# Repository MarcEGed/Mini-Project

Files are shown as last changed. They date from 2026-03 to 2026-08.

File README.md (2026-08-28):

# FELCOM

FELCOM is a secure handheld communication device built around the ESP32 and nRF24L01+. The firmware supports frequency-hopping communication, text chat, voice, synchronization, and RF testing.

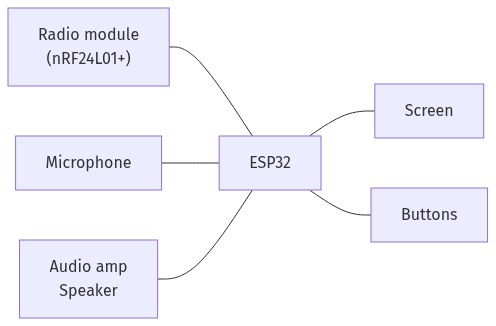
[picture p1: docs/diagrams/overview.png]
FELCOM system overview


## Repository layout

- [`FELCOM/`](FELCOM/) - PlatformIO firmware project.
- [`hardware/`](hardware/) - KiCad PCB design, fabrication outputs, and hardware images.
- [`docs/`](docs/) - Project notes, report sources and deliverables, diagrams, and hardware documentation.
- [`miscExperimenting/`](miscExperimenting/) - Earlier Arduino sketches and communication experiments.
- [`template/`](template/) - Typst report template and license.

## Documentation

- [`docs/felcom/AUDIO.md`](docs/felcom/AUDIO.md) - Audio pipeline, wiring, FEC behavior, and troubleshooting.
- [`docs/felcom/fhss.md`](docs/felcom/fhss.md) - FHSS channels, packet format, and synchronization design.
- [`docs/hardware/README.md`](docs/hardware/README.md) - Circuit assembly references.
- [`docs/report/`](docs/report/) - Typst report source, PDF report, and presentation.
- [`docs/diagrams/`](docs/diagrams/) - Mermaid source files and rendered report diagrams.

## Build and upload

Install PlatformIO, connect an ESP32 development board, and run the commands from `FELCOM/`:

```sh
pio run -e esp32dev
pio run -e esp32dev -t upload
```

The two communicating boards must run the same firmware. Use the Sync Test screen to synchronize their hopping schedule before using chat or audio.

## Hardware

The main hardware design is in [`hardware/fabrication_pcb/`](hardware/fabrication_pcb/). Consult the hardware documentation before assembling a board. Pin assignments and firmware configuration are in [`FELCOM/include/config.h`](FELCOM/include/config.h).

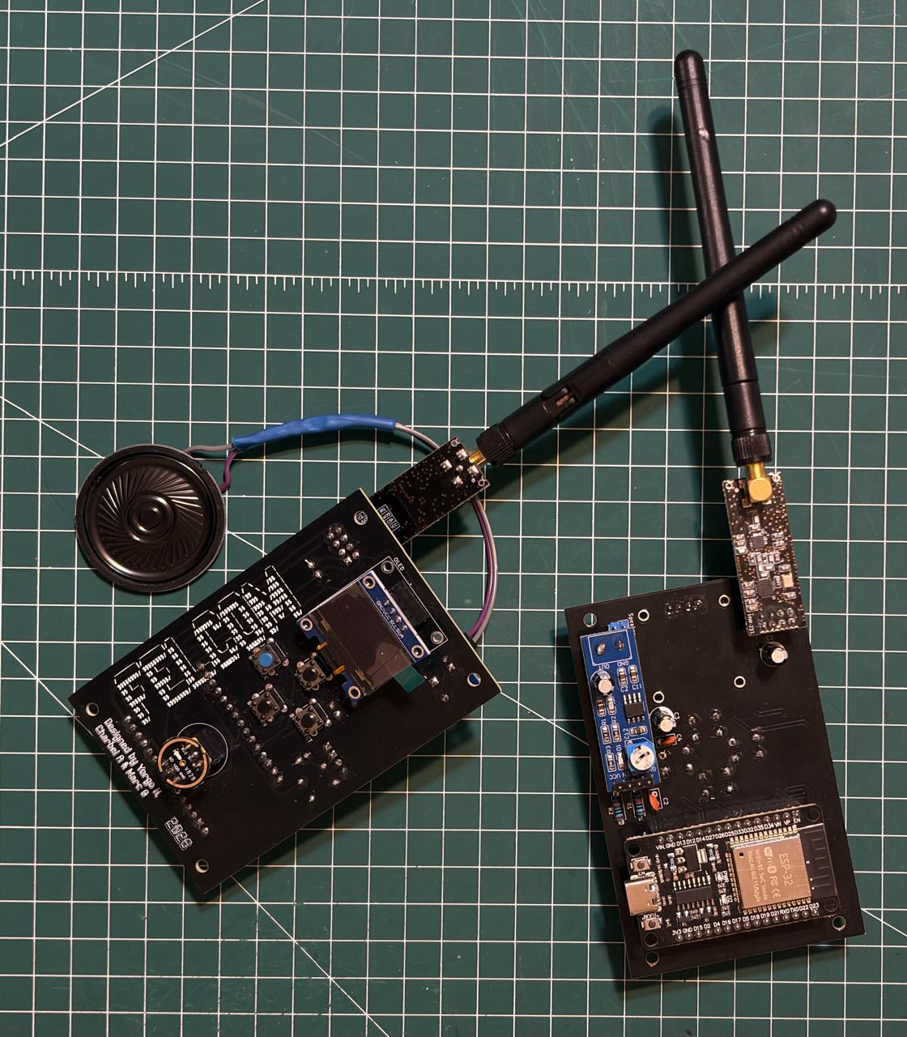
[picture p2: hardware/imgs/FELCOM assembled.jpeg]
Assembled FELCOM device


## Report

The current report and presentation are available in [`docs/report/`](docs/report/). The report source is compiled with Typst and uses the diagrams in [`docs/diagrams/`](docs/diagrams/) and images in [`hardware/imgs/`](hardware/imgs/).

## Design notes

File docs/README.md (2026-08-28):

# Documentation

This directory contains project documentation and presentation material.

- [`felcom/`](felcom/) - FELCOM design notes and audio research.
- [`diagrams/`](diagrams/) - Mermaid sources and rendered diagrams used by the report.
- [`hardware/`](hardware/) - Hardware assembly documentation.
- [`report/`](report/) - Report source, PDF, and presentation.

Firmware source and configuration remain in [`../FELCOM/`](../FELCOM/); KiCad source files remain in [`../hardware/`](../hardware/).

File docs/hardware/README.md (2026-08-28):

# Reference For Circuit Assembly

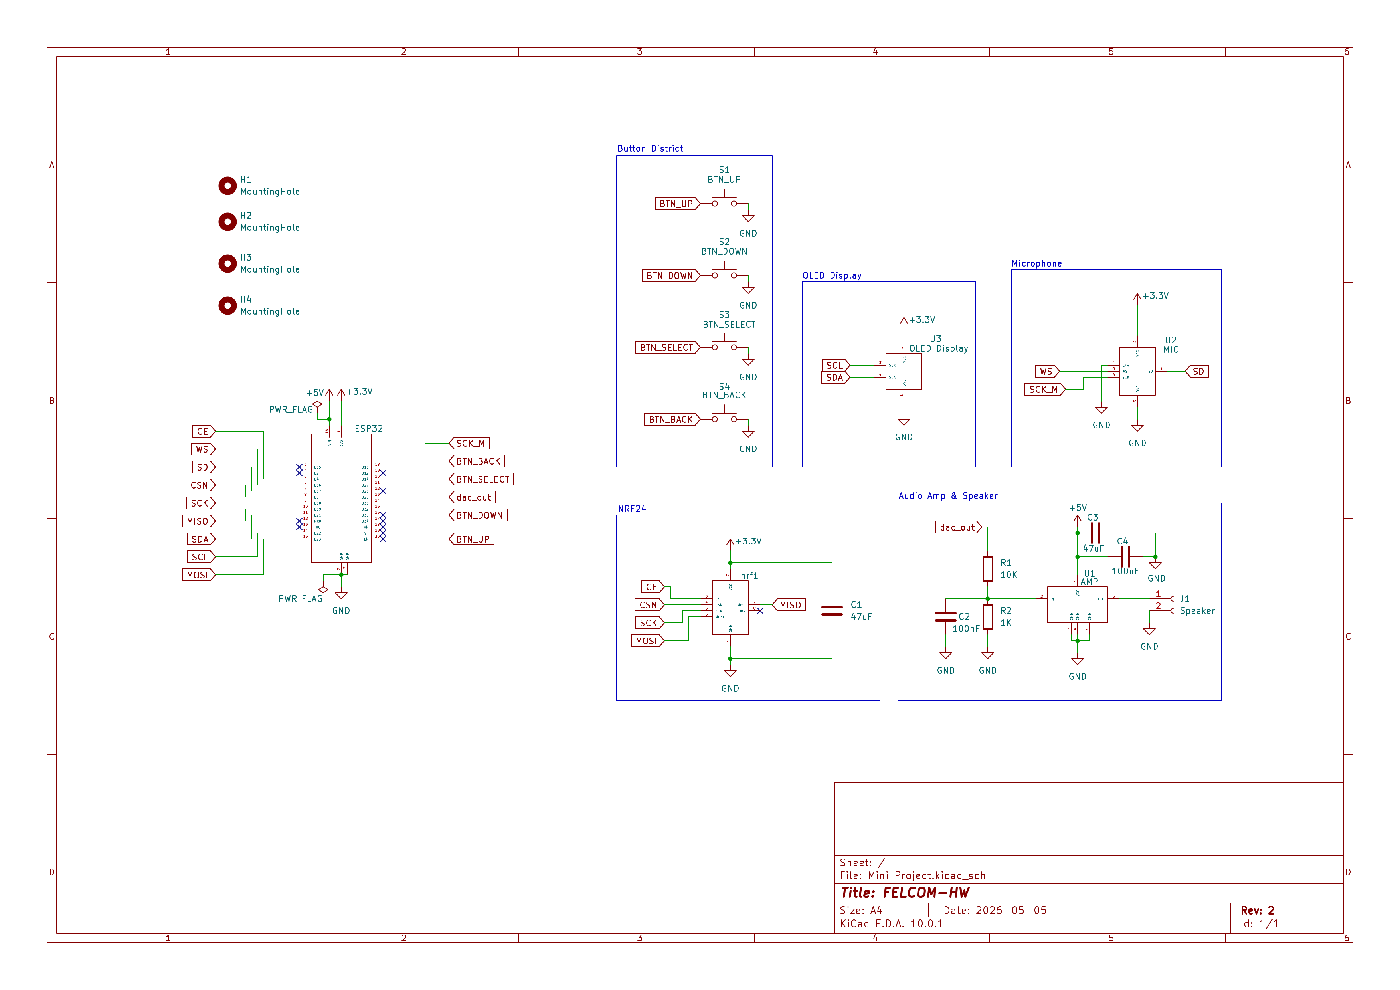
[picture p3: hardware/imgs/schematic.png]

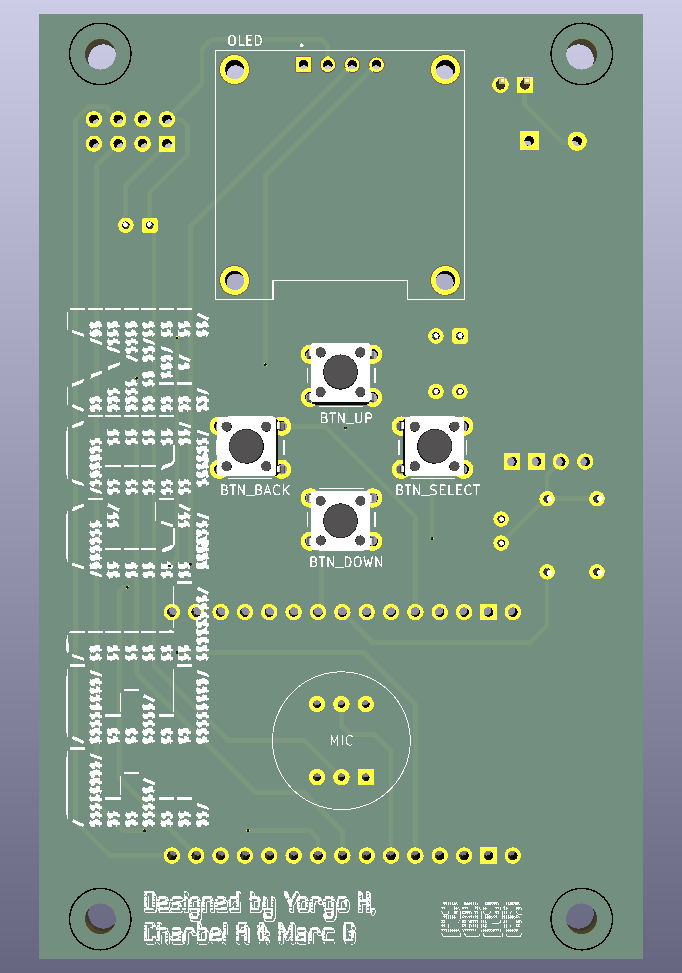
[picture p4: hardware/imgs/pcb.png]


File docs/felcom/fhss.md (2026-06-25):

# Channel selection
It is important for us to communicate on channels that don't suffer from interference.
The following is a list of nrf channels that falls between 2 wifi channels which should help us avoid interference.
```
13, 14, 15, 18, 19, 20, 23, 24, 25, 28, 29, 30, 33,
34, 35, 38, 39, 40, 43, 44, 45, 48, 49, 50, 53, 54,
55, 58, 59, 60, 63, 64, 65, 68, 69, 70, 77, 78, 79
```
![[Pasted image 20260512171434.png]]
## Nrf24 channels
The channel occupies a bandwidth of **1MHz at 1Mbps** and **2MHz at 2Mbps**. 
nRF24L01 can operate on frequencies from **2.400GHz** to **2.525GHz**

## Solution
With no way to physically check, using bands that are not used by WIFI will be the best choice.
This leaves with 2.5 -> 2.525
In terms of NRF24, **channel 100 -> 125**
# Synchronization
The biggest problem with FHSS is synchronization, many solutions are available, to name a few along with their problems:
1. Hoping on packet reception.
	- if we were to hop when a packet is received, when a receiver misses a packet, it will temporally become out of sync until the transmitter transmits a packet on the channel the receiver is currently listening on.
2. Hoping based on a timer.
	- When the clock drift becomes significant, the transmitter and the receiver will become out of sync with a really low probability to synchronize again.

Both of these suffer from the same problem, **new node synchronization**. 
When a new node connects to the network, for implementation:
1. The worst case is `len(hopping_channels)` messages lost, before successful synchronization.
2. The worst case is no synchronization ever!

A good implementation would be, one that minimizes the amount of messages lost due to the nodes being out of sync, and allows new nodes to hop on the network with no overhead or creating it's own network.

## Current Implementation

The current implementation uses a **manual synchronization** approach via the SyncTest UI:

- **Timer-based Hopping**: A hardware timer runs with a 500ms period (`timerAlarmWrite(COUNTER_TIMER, 500000, true)`). Nodes hop channels based on `readCounter() % HOPPING_CHANNELS_SIZE`, where `HOPPING_CHANNELS_SIZE = 6` (channels 110-115).

- **Manual Sync via UI**: In the SyncTest screen, pressing the button:
  1. Broadcasts an `ND_SYNC` packet containing the current counter value via `sendSync(counter)`
  2. Resets the local counter timer via `resetCounterTimer()`
  3. Flashes the SYNC button visually for 200ms

- **Receiving Sync**: When an `ND_SYNC` packet is received:
  1. The local counter is set to the received `timer_val` via `setCounter()`
  2. The received node is added to the synced nodes list
  3. The SYNC button flashes visually

- **ND_SYNC Packet Properties**:
  - Sent as **raw/unprotected** (FecScheme::NONE) to ensure it's never dropped by CRC validation
  - Contains: `timer_val` (int64_t), `nbSyncedNodes` (uint8_t), and `syncedNodes[10]` (array of node IDs)
  - Broadcast to all nodes (dst_node_id = 0xFF)

- **Synchronization Mechanism**: All nodes that receive the sync packet reset their counter to the same value, ensuring they all hop to the same channel at the same time. The counter increments every 500ms, and channel changes occur when `counter % 6` changes.

- **Limitations**:
  - Requires manual user intervention to synchronize
  - No automatic drift compensation between hops
  - No automatic out-of-sync detection
  - New nodes must manually sync via the SyncTest UI
  - Clock drift between nodes will eventually cause desynchronization

This approach prioritizes simplicity and reliability (sync packets are never dropped) over automatic synchronization.

# Network Layer
## packet format
32 Bytes can be used.

| section name | size |
| --- | --- |
| src_node_id  | 1 byte |
| dst_node_id  | 1 byte |
| packet_type  | 0.5 bytes |
| FEC | 1.5 bytes |
| data | 28 bytes  |

*Note: In C++, `packet_type` and `FEC` will be packed using bit-fields (e.g., `uint16_t type: 4; uint16_t fec: 12;`) to fit neatly into 2 bytes.*

### Packet Type
| Type name |
| --------- |
| PONG      |
| CHAT      |
| AUDIO     |
| ND_SYNC   |
| TEST      |
| ACK       |

## protocol
- Nodes implement CSMA using `bool RF24::testRPD(void)` along with a **random backoff** mechanism (1-10ms) before transmission to handle collisions gracefully. CSMA is **disabled for audio packets** to avoid blocking the real-time audio loop.
- `dst_node_id`, if set to `0xFF`, means the packet is broadcast and is meant for everyone on the network.
- **Automatic drift compensation is not implemented** - nodes do not adjust their timers on packet reception.
- **Out-of-sync detection is not implemented** - nodes do not detect when they are out of sync or automatically broadcast `ND_SYNC` packets.
- **`ND_SYNC` Packets**: Contain the hardware timer counter value in the data section. In the current implementation:
  - Broadcast to all nodes (dst_node_id = 0xFF)
  - Sent as raw/unprotected (FecScheme::NONE) to prevent CRC drops
  - Used only in the SyncTest UI for manual synchronization
  - The counter value is always the sender's current counter (never -1)

To join a network, nodes currently must:
1. Use the SyncTest UI to manually synchronize with an existing network by pressing the SYNC button
2. All nodes will then reset their counter to the same value and begin hopping in sync

If nodes are not synchronized, they will be on different channels at different times, and communication will fail until manual synchronization is performed.

## Solution
- Low number of hoppable channels (6 channels: 110-115).
- Timer based hopping using a hardware timer (500ms period).
- Manual synchronization via ND_SYNC packets broadcast from the SyncTest UI.
- `ND_SYNC` used for manual synchronization and tracking which nodes are in sync.

# Implementation Plan

- **List of hoppable channels**: `110, 111, 112, 113, 114, 115`
- **Timer frequency**: `500ms` (500000 microseconds, ~3s full rotation across 6 channels)

## Steps
1. ~~**Packet Structure Update**~~ (Done): Define the new 32-byte generic packet struct using C++ bit-fields (`uint16_t type: 4; uint16_t fec: 12;`) to handle the `packet_type` and `FEC`. Protocol types live in `include/protocol.h`.
2. ~~**Address Filtering**~~ (Done): Update the payload size to 32 bytes (`sizeof(FHSSPacket)`) in `setup()`. In `read()`, cast incoming data to `FHSSPacket*` and discard packets where `dst_node_id` is neither our node ID nor the broadcast ID (`0xFF`).
3. ~~**CSMA & Random Backoff**~~ (Done): Implement carrier sensing using `RF24::testRPD()` in `transmitPacket()`. Before transmitting, switch briefly to `RECEIVE` mode, verify the channel is clear, and if busy apply a random backoff delay (1-10ms) before retrying. Note: CSMA is disabled for audio packets via `transmitAudioPacket()`.
4. ~~**Setup Timer & Hopping Sequence**~~ (Done): Initialize the hardware timer with a 500ms period (`timerAlarmWrite(COUNTER_TIMER, 500000, true)`). The main loop reads the counter and changes channels based on `readCounter() % HOPPING_CHANNELS_SIZE`.
5. ~~**Manual Synchronization**~~ (Done): 
	- Implement SyncTest UI with manual sync button
	- Broadcast `ND_SYNC` packet with current counter value via `sendSync()`
	- Reset local counter on sync packet reception via `setCounter()`
	- Track synced nodes in `syncedNodes[]` array
6. **Synchronization Maintenance (Implicit Piggybacking)**: 
    - **Not implemented**: Automatic drift compensation on packet reception
    - **Not implemented**: Consecutive silent hop tracking
7. **Out-of-Sync Handling**: 
    - **Not implemented**: Automatic detection and recovery via `ND_SYNC` broadcast

## Relevant files
- `include/config.h` — Hopping channel configuration (`HOPPING_CHANNELS`, `HOPPING_CHANNELS_SIZE`).
- `include/protocol.h` — Protocol-level packet types, `FHSSPacket`, `NDSyncData`, `FecScheme`.
- `lib/ftimers/ftimers.h` / `ftimers.cpp` — Hardware timer initialization, counter read/write/reset.
- `lib/transceiver/transceiver.h` — FHSS state machine, synced nodes tracking, packet helpers.
- `lib/transceiver/transceiver.cpp` — FHSS hopping, CSMA, address filtering, `sendSync()`, `writeRaw()`.
- `src/ui/SyncTestUI.h` / `SyncTestUI.cpp` — Manual synchronization UI with SYNC button.
- `src/chat/ChatMessage.h` — Chat payload struct.
- `src/pong/PongMessage.h` — Pong payload struct.
- `src/rf_test/TestMessage.h` — RF test payload struct.
- `src/main.cpp` — Main loop with channel hopping logic based on counter modulo.

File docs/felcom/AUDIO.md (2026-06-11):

# FELCOM Audio + FEC — What's New

This documents the **real-time voice** feature and the **FEC layer** it rides on,
added on top of the FHSS transceiver. If you just want to use it, jump to
[How to use it](#how-to-use-it). If something doesn't work, read
[Hardware & gotchas](#hardware--gotchas) first — most issues are wiring/sync.

---

## TL;DR

- New **AUDIO** screen in the menu (between `SYNC TEST` and `ABOUT`): a
  half-duplex walkie-talkie. One node **TALKS**, the other **LISTENS**; press
  **SELECT** to toggle role, **BACK** to exit.
- Audio is **8 kHz / 8-bit mono PCM**, captured from the INMP441 mic, sent over
  the existing radio, and played out the ESP32 DAC → amp → speaker.
- It is **non-blocking** (no FreeRTOS tasks) — capture/transmit/receive/playback
  are cooperative steps pumped from `loop()`, so FHSS hopping still works.
- It rides the transceiver's **FEC**: every audio packet is CRC-protected and
  carries XOR parity so one lost packet per block of 4 can be reconstructed.

---

## How to use it

Both boards run the **same firmware** (`env:esp32dev`). Flash each:

```
pio run -e esp32dev -t upload --upload-port COM3
pio run -e esp32dev -t upload --upload-port COM4
```

1. **Sync the two boards first.** Audio rides FHSS, so the nodes must be on the
   same channel-hopping schedule (exactly like chat). On *both* boards open
   **SYNC TEST** and press **SYNC**.
2. On both boards go **back to the menu → AUDIO**.
3. On one board press **SELECT** → it shows **TALKING**. Leave the other on
   **LISTENING**.
4. Talk into the mic; you hear it on the listener's speaker.

> If you hear nothing, the boards have most likely **drifted out of sync**
> (clock drift, same limitation as chat) — re-run SYNC. See gotchas below.

---

## Hardware & gotchas

### Wiring (per board)
| INMP441 mic | ESP32 |
| --- | ----- |
| SCK | GPIO13 |
| WS | GPIO16 |
| SD | GPIO17 |
| L/R | **GND** (selects the left slot) |
| VDD / GND | 3.3 V / GND |

| Audio out | ESP32 |
| --- | ----- |
| DAC → amp (LM386) input | **GPIO25** (DAC1) |

These pins live in `include/config.h` (`I2S_*_PIN`, `DAC_OUT_PIN`).

### The two gotchas that cost us the most time
1. **`I2S_CHANNEL_FMT_ONLY_LEFT` returns silence on our DevKit boards.** This is
   a known ESP32 *legacy* I2S quirk. We capture in **stereo
   (`RIGHT_LEFT`) and use `AUDIO_I2S_SLOT_INDEX`** to select the DMA slot. If the
   mic reads all zeros, this is almost always why.
2. **DAC is on GPIO25, not 26.** The amp is wired to DAC1 (GPIO25).

### Other things to know
- **Sync is required.** No sync ⇒ the two nodes hop to different channels ⇒ no
  audio. Clock drift will desync them over time; just re-SYNC.
- **Half-duplex.** Only one node should be TALKING at a time; if both talk,
  neither listens.
- **Quality.** It's 8 kHz / 8-bit voice — fine for intelligible speech, not
  music. Expect some hiss and occasional clicks at channel-hop boundaries.

---

## Architecture

```
loop():
  hop channel (FHSS, from the 500 ms counter)        ── unchanged
  AUDIO screen tick → audio::update()                ── non-blocking
        │
   TALK │                              LISTEN │
        ▼                                     ▼
  i2s_read(timeout 0)  → DC-removal + gain   xcvr.audioRx()  ← CRC + XOR recover
        → 8-bit → accumulate 24 samples       → RX ring (4096)
        → xcvr.audioTx(AudioPayload)          → micros-paced 8 kHz → DAC (GPIO25)
              (CRC + XOR block FEC + CSMA)
```

- **Capture** (`audio.cpp`): non-blocking `i2s_read` (timeout 0) so the loop
  never stalls; DC-offset EMA `(dc*63 + s)/64`, gain `(centered*AUDIO_GAIN)>>16`,
  clamp to 8-bit. 24 samples → one `AudioPayload`.
- **`AudioPayload`** (`include/protocol.h`): `uint16_t seq + uint8_t samples[24]`
  = 26 bytes, which exactly fills the FEC "user region" (the last 2 of the
  28 data bytes hold the CRC).
- **Playback**: `xcvr.audioRx()` returns FEC-recovered payloads; samples go into
  a ring buffer that is drained to the DAC at exactly 8 kHz using `micros()`
  pacing (no extra hardware timer — the FHSS counter uses one already).
- **FHSS**: audio uses the normal hop logic in `loop()`; nothing audio-specific
  hops.

---

## The FEC layer (what audio rides on)

FEC is **owned by the transceiver** — the app never calls FEC functions
directly, it just uses `xcvr.write` / `writeReliable` / `read` / `audioTx` /
`audioRx`. Three complementary mechanisms, applied per packet type:

| Packet type | CRC16 | ARQ (retransmit) | XOR block | Why |
| --- | :---: | :---: | :---: | --- |
| CHAT | ✓ | ✓ | ✗ | infrequent, must be exact |
| ND_SYNC | ✗ (raw) | ✗ | ✗ | timing broadcast; must stay forgiving |
| PONG | ✓ | ✗ | ✗ | frequent; ARQ would backlog |
| AUDIO | ✓ | ✗ | ✓ | real-time; forward recovery only; bypasses CSMA backoff |
| TEST (BER)  | ✗ (raw) | ✗ | ✗ | measures real bit errors |
| ACK | ✓ | ✗ | ✗ | small control packet |

- **CRC16-CCITT** lives in the last 2 of the 28 data bytes (the air frame is
  unchanged at 32 bytes). The 12-bit `fec` header field carries metadata only
  (scheme / XOR block id / slot index), not the CRC.
- **XOR block FEC** (audio): 4 data packets + 1 parity packet; recovers exactly
  one lost packet per block.
- **ARQ** (chat): blocks waiting for an ACK and retransmits; not used for audio
  (too much latency).

See `lib/fec/` for the implementation and `lib/transceiver/transceiver.h` for
the public API.

---

## Tuning & debugging

- **Mic slot:** `AUDIO_I2S_SLOT_INDEX` in `include/config.h` selects which
  stereo DMA slot is treated as the INMP441 sample. With L/R tied to GND the
  mic should be on the left slot, but ESP32 legacy I2S can expose that as
  buffer index `0` or `1` depending on board/framework behavior. If diagnostics
  show `mic` increasing but `peak` near zero, try the other slot before changing
  gain.
- **Mic volume:** `AUDIO_GAIN` in `include/config.h` (currently `18`).
  Higher = louder but more clipping/hiss; lower = cleaner but quieter.
  This is a *capture-side* setting, so only the **talking** board needs
  reflashing when you change it. If `clip` rises quickly while talking, reduce
  `AUDIO_GAIN`.
- **Local mic monitor:** `AUDIO_LOCAL_MONITOR` in `include/config.h` plays the
  same 8-bit samples being transmitted out the local DAC while TALKING. This is
  useful for separating mic/I2S/gain problems from radio/FEC problems. If local
  monitor is still choppy, temporarily set `AUDIO_RADIO_TX_ENABLE` to `0`; that
  tests only mic → DSP → DAC without nRF24/FEC transmit stalls. If sidetone has
  too much delay, lower `AUDIO_LOCAL_MONITOR_MAX_QUEUED`; if it sounds too
  rough, raise it a bit.
- **Serial debug:** set `AUDIO_SERIAL_DEBUG` to `1` in `include/config.h` to
  print every 2 s: role, TX/RX payload counts, I2S read activity, mic sample
  count/peak/clips, RX ring level, underruns/overruns, and FEC counters
  (`CRC ok/bad`, `AUDIO blk/rec/lost`). Keep it `0` for normal playback because
  serial printing stalls the cooperative audio loop and causes audible skips.
  - `i2s` first/second number = non-empty reads / total reads. If total rises
    but non-empty stays low, the loop is polling faster than DMA fills; this is
    usually OK. If both stay at 0 while TALKING, capture is not running.
  - `mic` should rise while TALKING; `peak` should move when you speak. Near-zero
    `peak` usually means the wrong I2S slot or mic wiring/power.
  - `clip` rising quickly means the 8-bit conversion is saturating; lower
    `AUDIO_GAIN`.
  - `under` rising on LISTEN means playback is starved: radio/FEC is not
    delivering enough samples, sync is bad, or debug/logging is stalling audio.
  - `over` rising means the RX jitter ring is filling faster than playback can
    drain it.
  - `CRC bad` = corrupt packets dropped, `rec` = packets XOR rebuilt,
    `lost` = losses XOR couldn't fix (these become gaps).

---

## Files

**New**
- `lib/adio/audio.h`, `lib/adio/audio.cpp` — the non-blocking audio subsystem.
- `src/ui/AudioUI.h`, `src/ui/AudioUI.cpp` — the AUDIO screen.

**Changed**
- `include/config.h` — audio pins/params (`AUDIO_GAIN`, `AUDIO_RX_RING`, …),
  `DAC_OUT_PIN = 25`.
- `src/main.cpp` — `audio::begin()`, the AUDIO menu entry + mode tick, and the
  opt-in debug line.
- `src/ui/ui.{h,cpp}`, `src/ui/MenuUI.{h,cpp}` — the AUDIO menu item + dispatch.

---

## Known limitations / next steps

- **Skipping at hop boundaries.** Each 500 ms hop can drop the in-flight packet;
  XOR only recovers one loss per block of 4. Options if it's too choppy:
  pin AUDIO mode to a fixed channel, or add a short RX pre-buffer.
- **Sync drift** desyncs the nodes over time — re-SYNC as needed.
- **Half-duplex only**; no push-to-talk hardware button yet (toggle via SELECT).
- **Audio TX bypasses CSMA backoff** to avoid millisecond stalls at the audio
  packet rate. If both nodes transmit audio at once, collisions are expected;
  keep AUDIO half-duplex.

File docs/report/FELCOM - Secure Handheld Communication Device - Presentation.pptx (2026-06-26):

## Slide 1

FELCOM

A Secure Handheld Communication Device

Marc Gedeon · Yorgo Hassabou · Charbel Assaad
Mini-Project · 2025 / 2026
Presented to: Dr. Hadi Jerdek
Lebanese University · Faculty of Engineering


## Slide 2

Outline

1 Motivation & goals
2 System overview
3 Frequency hopping & sync
4 Packet protocol

FELCOM · Secure Handheld Communication Device

5 Forward error correction
6 Security & applications
7 Real-time audio
8 Results & conclusion

2

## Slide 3

Why FELCOM?

- Networks rely on fixed infrastructure: a single point of failure.
- Off-grid need: a direct link, no third party.
- A fixed-frequency radio is easy to jam and intercept.
- Answer: spread spectrum, constantly change the frequency.

FELCOM · Secure Handheld Communication Device

3

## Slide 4

What We Built

- Text + live voice over 2.4 GHz, no infrastructure.
- FHSS: jam and detection resistance.
- Custom 32-byte packet protocol with FEC.
- Text encryption, BER test, and a Pong demo.

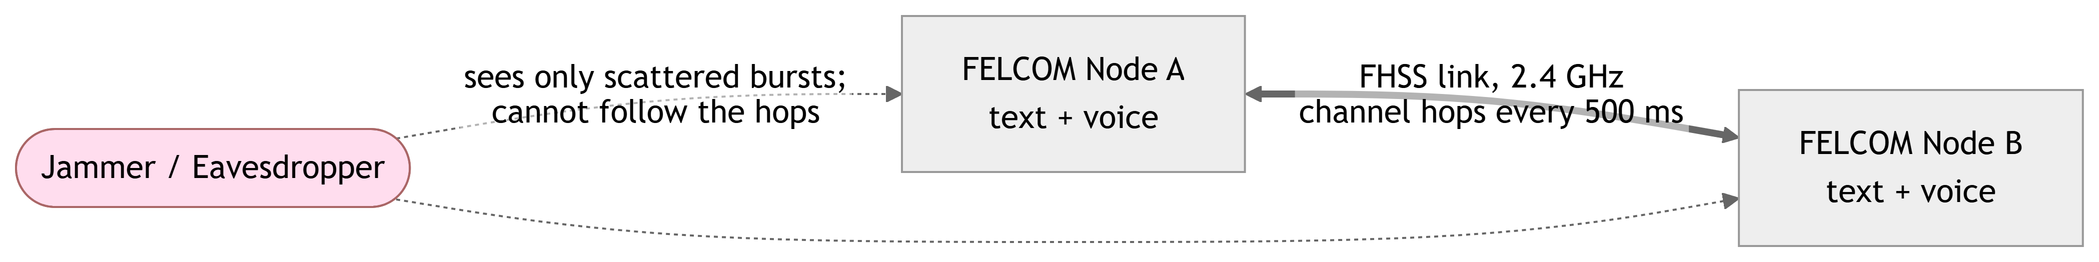
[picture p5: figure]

FELCOM · Secure Handheld Communication Device

4

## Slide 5

System Overview

- ESP32 + nRF24L01+ 2.4 GHz radio (SPI).
- INMP441 mic, DAC + LM386 + speaker.
- OLED + buttons, custom PCB.
- Layered firmware, non-blocking loop.

FELCOM · Secure Handheld Communication Device

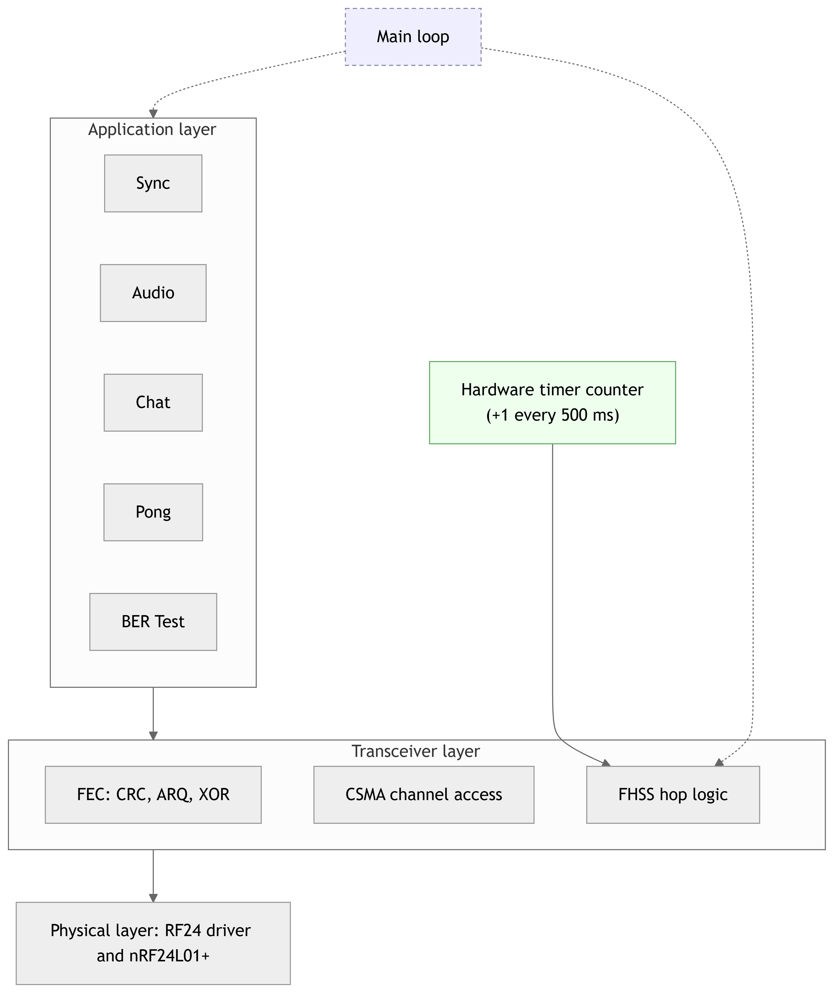
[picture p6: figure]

5

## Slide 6

Frequency Hopping & Synchronization

- Six channels (110 to 115), above Wi-Fi.
- Hop every 500 ms; full sweep in 3 s.
- A jammer only spoils the few matching hops.
- A shared counter keeps both nodes aligned.
- Manual Sync once, then stable: no drift over 3 h.

FELCOM · Secure Handheld Communication Device

// hop every 500 ms from
// the shared counter
slot = readCounter() % 6;
setChannel(HOPPING[slot]);

6

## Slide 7

One 32-Byte Frame for Everything

- Fixed 32-byte frame (the nRF24 maximum).
- Header: src, dst, packet type, FEC metadata.
- 28 data bytes; one frame for text, voice, control (0xFF = broadcast).

src
1 B

dst
1 B

type + fec
2 B

data
28 B

user payload
26 B

CRC-16
2 B

CRC in the last 2 of the 28 data bytes; ARQ uses the first 2 for a sequence number.

FELCOM · Secure Handheld Communication Device

7

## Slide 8

Forward Error Correction

- Our own error control (radio CRC and ACK off).
- CRC-16: detect and drop corruption.
- ARQ (chat): retransmit until acknowledged.
- XOR (audio): rebuild one lost packet per block of four.

FELCOM · Secure Handheld Communication Device

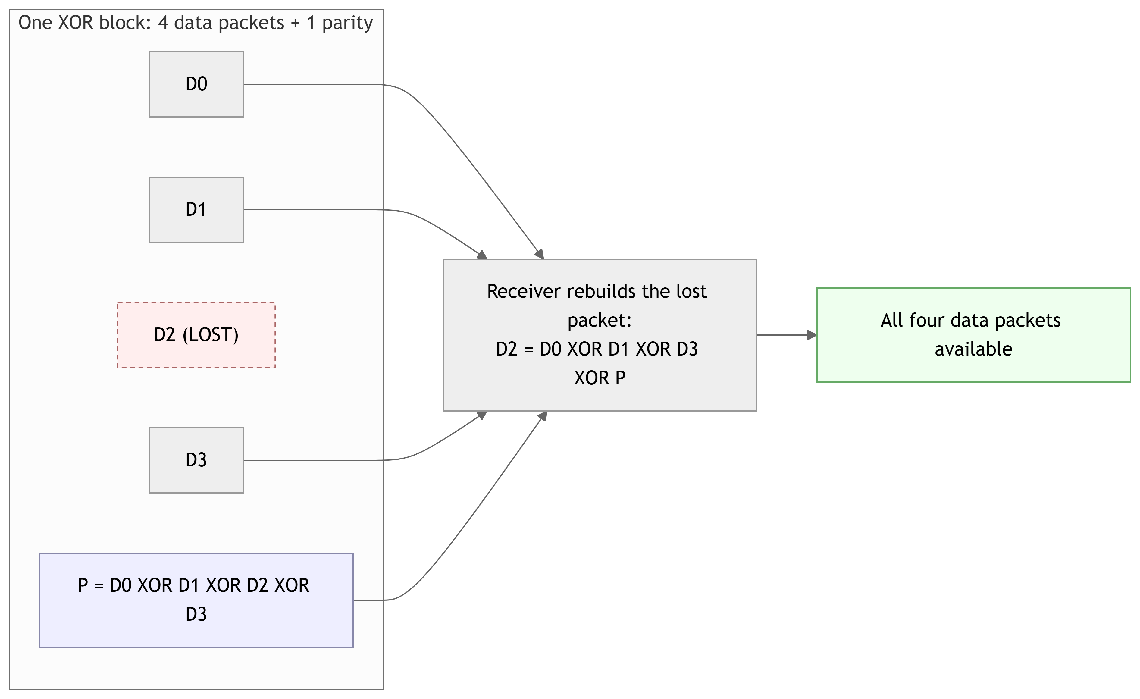
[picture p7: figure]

8

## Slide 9

Security & Applications

Security

- XOR cipher on chat text.
- Obfuscation, not strong crypto.
- Hopping makes capture hard.

FELCOM · Secure Handheld Communication Device

Application Modes

- Sync: align the hop counters.
- Chat: reliable encrypted text.
- Audio: voice walkie-talkie.
- Pong: real-time game.
- RF/BER Test: link diagnostics.

10

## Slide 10

Real-Time Voice

- Half-duplex walkie-talkie.
- 8 kHz, 8-bit voice.
- Non-blocking: streams while hopping.
- Protected by CRC + XOR FEC.

FELCOM · Secure Handheld Communication Device

Transmit (talk)

Receive (listen)

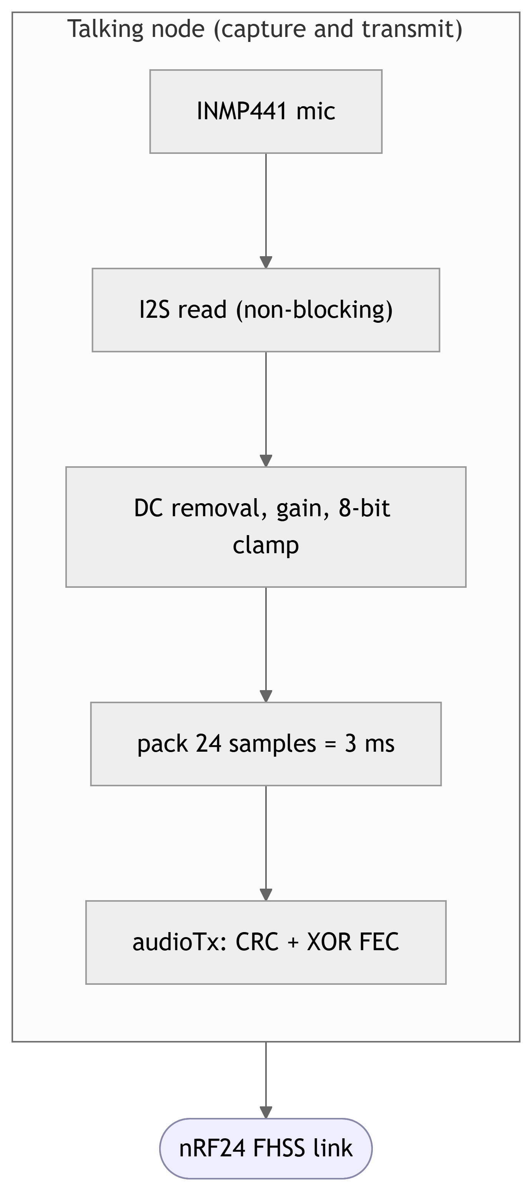
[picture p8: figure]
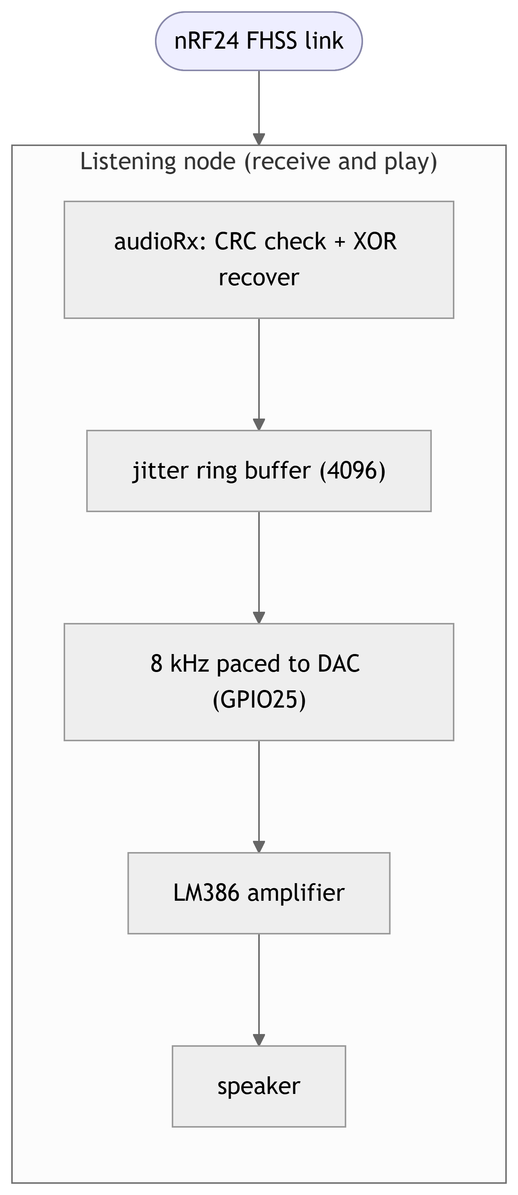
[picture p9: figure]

9

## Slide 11

Results

Metric | FHSS | No FHSS
Delivered | 85.4% | 48%
Lost | 14.6% | 52%
Bit-error rate | 1% | 19%

Error correction

- ARQ: 29 / 32 delivered, 0 corrupt.
- XOR: 516 packets rebuilt.
- CRC: 2,027 corrupt dropped.

FHSS cut packet loss from 52% to 14.6% on the same channel set.

FELCOM · Secure Handheld Communication Device

11

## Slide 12

Challenges & Future Work

Challenges

- Sync: manual alignment (auto deferred).
- Audio pipeline: DAC rework, skip CSMA.
- nRF24L01+ modules unreliable.

FELCOM · Secure Handheld Communication Device

Future Work

- AES authenticated encryption.
- Automatic synchronization.
- Larger buffer / stronger code for audio.

12

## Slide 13

Conclusion

- Jam-resistant text and voice on cheap hardware.
- FHSS is the key: packet loss 52% to 14.6%.
- FEC matched per traffic type: CRC, ARQ, XOR.
- Built on a custom PCB, validated on real hardware.

Future work: AES encryption and automatic synchronization.

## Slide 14

References

[1] Nordic Semiconductor, nRF24L01+ Transceiver Product Specification.
[2] Espressif Systems, ESP32 Technical Reference Manual and Datasheet.
[3] InvenSense (TDK), INMP441 I2S Microphone Datasheet.
[4] Texas Instruments, LM386 Audio Power Amplifier Datasheet.
[5] TMRh20, RF24: Optimized driver for nRF24L01(+) (open source).
[6] Lamarr & Antheil, Secret Communication System, U.S. Patent 2,292,387, 1942.
[7] ITU-T Recommendation V.41, CRC-16-CCITT.
[8] A. Goldsmith, Wireless Communications, Cambridge University Press.

FELCOM · Secure Handheld Communication Device

14

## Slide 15

Acknowledgments

We would like to thank Dr. Hadi Jerdek, for his supervision of this project and for the valuable knowledge he shared with us through the telecommunications courses he taught.
We also thank the Lebanese University for allowing us to use its open air to test our devices.

Thank you · Questions?

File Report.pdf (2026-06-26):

2025/2026

# FELCOM: A Secure Handheld Communication Device

Mini-Project

Prepared By:
Marc Gedeon
Yorgo Hassabou
Charbel Assaad

Presented To:
Dr. Hadi Jerdek

## Table of Contents

i

## Table of Figures

Figure 1 Two handhelds communicating directly over a frequency-hopping link . . . . 2

Figure 3 Full hardware schematic of a FELCOM unit (ESP32, nRF24L01+,

ii

## Abstract

FELCOM is a handheld radio that provides secure, text and voice communication in the 2.4 GHz ISM band. Each unit is built around an ESP32 microcontroller driving an nRF24L01+ transceiver, an INMP441 I2S microphone, a DAC, amplifier and speaker audio chain, an OLED display and tactile controls, all integrated on a custom PCB. To resist narrowband jamming and lower the probability of interception, the link continuously hops across six channels using Frequency-Hopping Spread Spectrum (FHSS). The nodes stay aligned by a shared, timer-driven hopping schedule. A custom 32-byte packet format multiplexes text, voice and control traffic over the same radio and carries a compact forward-error-correction header. A layered FEC subsystem in the transceiver provides reliability: a CRC-16 detects corruption on every protected packet, an automatic-repeat-request (ARQ) scheme guarantees exact delivery of chat messages, and an XOR block code reconstructs lost real-time audio packets without retransmission. Voice is captured as 8 kHz 8-bit PCM. Chat text is obfuscated with a lightweight XOR cipher. A built-in bit-error-rate (BER) test mode and live FEC counters allow link quality to be measured and analysed. The result demonstrates that robust, jam-resistant, low-cost digital voice and messaging can be realized entirely on commodity hardware.

iii

## 1 Introduction

### 1.1 Background and Motivation

Reliable communication is usually taken for granted because it rests on a large, fixed infrastructure: cell towers, base stations, the Internet backbone. That infrastructure is also a single point of failure. In a natural disaster, in a remote area, or in any situation where the network is congested, censored or deliberately disabled, the same devices that work everywhere suddenly work nowhere. This motivates off-grid communication: a direct radio link between two people that depends on no third party.

A direct radio link, however, is exposed. A fixed-frequency transmitter is easy to locate, easy to intercept and trivial to jam, since a single interfering source on the right frequency is enough to silence it. The classical answer to this problem is spread spectrum. By rapidly and unpredictably changing the carrier frequency, a frequency-hopping system spreads its energy across a wide band: a narrowband jammer can only spoil the few hops that happen to land on its frequency, and an eavesdropper who does not know the hopping sequence sees only brief, scattered bursts. The same principle underlies Bluetooth today.

### 1.2 The Project

FELCOM implements these ideas on inexpensive, off-the-shelf hardware. It lets two units exchange text messages and live voice directly over the 2.4 GHz band. The link uses FHSS for resilience, employing a custom packet protocol with forward error correction, and obfuscates text with a lightweight cipher. Two additional modes—a real-time multiplayer Pong game and an RF/BER test screen—validate low-latency bidirectional traffic and raw link quality, respectively.

### 1.3 Objectives

The project aims to:

- build a working two-node handheld system on an ESP32 + nRF24L01+ platform,
- implement FHSS with a synchronization mechanism,
- define a flexible packet protocol that multiplexes text, voice, and control traffic over one radio,
- add a layered forward-error-correction subsystem (detection, retransmission, and forward recovery) matched to each traffic type,
- provide a debug mode that measures packet loss and bit-error rate, and
- integrate everything onto a custom PCB.

### 1.4 Technology and Methodology

The system uses the Espressif ESP32 (dual-core, hardware timers, I2S, and DAC peripherals) paired with the Nordic nRF24L01+, a 2.4 GHz GFSK transceiver that performs modulation in hardware and exposes 125 selectable 1 MHz channels, enabling FHSS.

## 2 System Overview

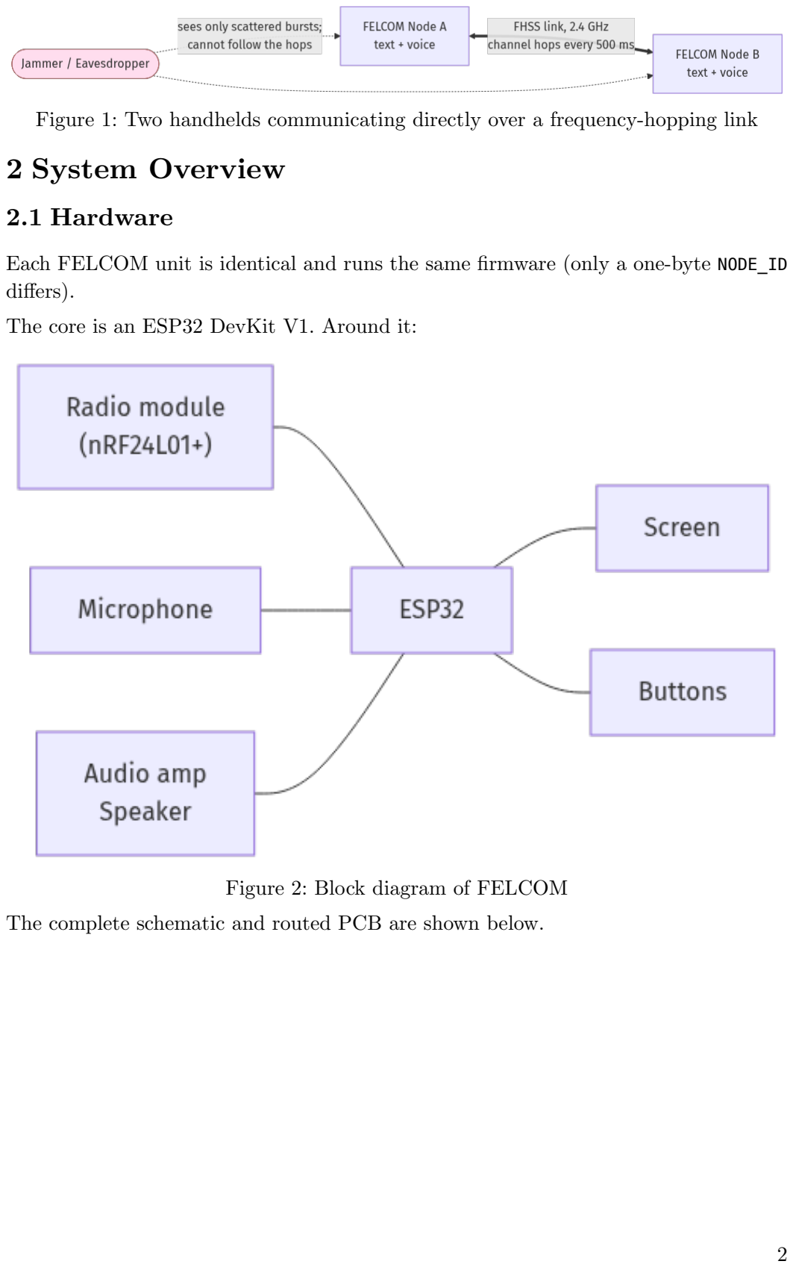
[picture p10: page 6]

Figure 1: Two handhelds communicating directly over a frequency-hopping link

### 2.1 Hardware

Each FELCOM unit is identical and runs the same firmware (only a one-byte NODE_ID differs).

The core is an ESP32 DevKit V1. Around it:

Figure 2: Block diagram of FELCOM

The complete schematic and routed PCB are shown below.

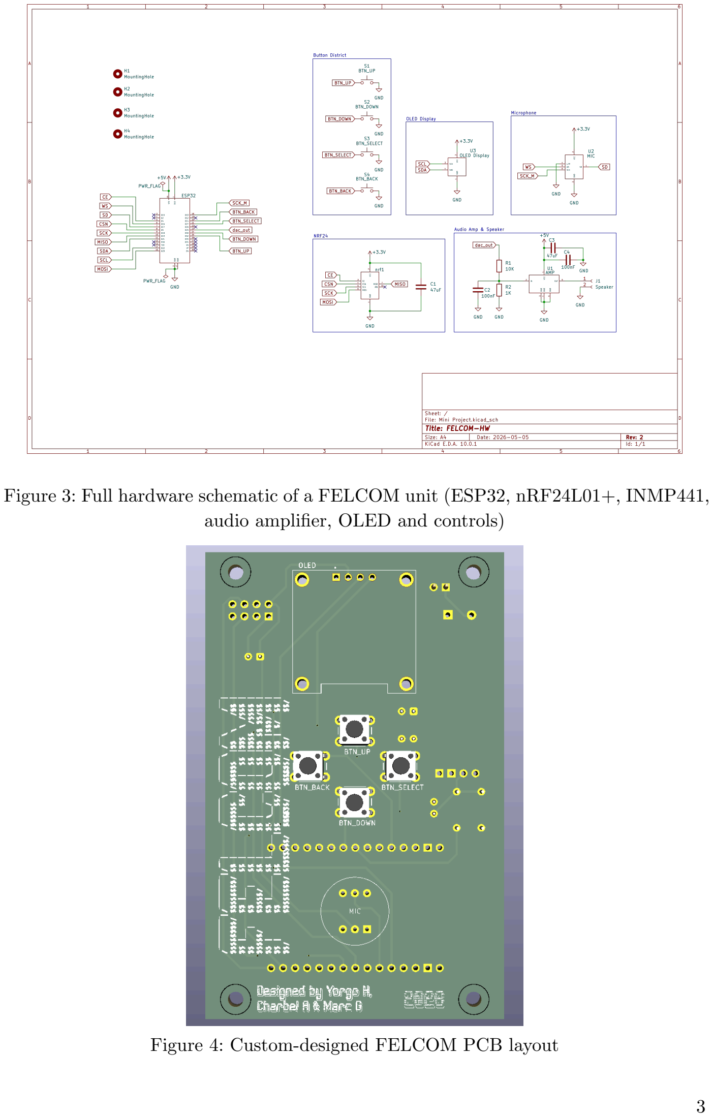
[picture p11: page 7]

Figure 3: Full hardware schematic of a FELCOM unit (ESP32, nRF24L01+, INMP441, audio amplifier, OLED and controls)

Figure 4: Custom-designed FELCOM PCB layout


Figure 5: Two FELCOM units fully assembled

### 2.2 Firmware Architecture

The firmware is organized into clear layers, keeping each block (FHSS, framing, FEC, audio) independent and testable:

- Physical layer: the RF24 driver and the raw nRF24L01+ register access.
- Transceiver layer (lib/transceiver): performs channel access (CSMA), address filtering, and all error-control logic. The transceiver integrates the FEC subsystem, so application code never calls FEC routines directly, it simply uses write,
writeReliable, read, audioTx, and audioRx.
- Application layer: chat, audio, Pong, Sync, and the RF/BER test, each with its own payload struct and OLED screen.

The main loop uses a cooperative, non-blocking design. Channel hopping, UI input, message handling, and audio capture/playback are all short steps pumped from a single loop(). A hardware timer increments a free-running counter every 500 ms, the loop reads it and hops when it changes. Since no step blocks, hopping always occurs on time, even while audio streams. This is the main constraint driving the architecture.

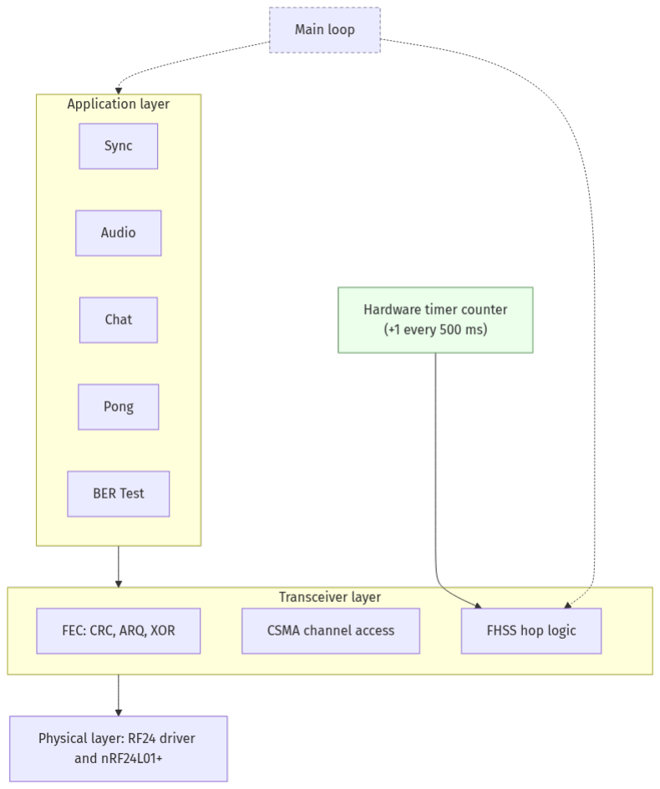
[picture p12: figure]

Figure 6: Layered firmware architecture and non-blocking main loop

## 3 Frequency-Hopping Spread Spectrum

FHSS is the heart of the project and provides its jam and detection resistance. The nRF24L01+ handles modulation in hardware while the firmware continuously changes the active channel from the transceiver’s 125 available options.

### 3.1 Channel Selection

The 2.4 GHz band is crowded, primarily by Wi-Fi, whose channels are 20-22 MHz wide. Blind hopping would place many transmissions inside Wi-Fi channels, causing losses. The system therefore restricts hopping to the top of the band (approximately 2.51 GHz, corresponding to nRF24L01+ channels 110-115), which sits above standard Wi-Fi allocations and is typically quiet. The current build uses a deliberately small hop set of six channels, {110, 111, 112, 113, 114, 115}, trading some spreading gain for easier and faster synchronization.

### 3.2 Timer-Driven Hopping

All nodes share the same hop schedule. A hardware timer increments a global counter every 500 ms, the active channel is simply HOPPING_CHANNELS[counter mod 6]. Since all units derive the channel from the same counter value, they remain synchronized as long as their counters match. A full sweep through all six channels takes 3 seconds.

// Every 500 ms the shared timer counter ticks; the channel follows it. uint32_t slot = readCounter() % HOPPING_CHANNELS_SIZE; xcvr.setChannel(HOPPING_CHANNELS[slot]); // one of 110..115

Listing 1: Timer-driven hopping: both nodes derive the channel from the same free-running counter, staying aligned without exchanging synchronization packets

### 3.3 Synchronization

Synchronization is critical for FHSS. The chosen approach uses timer-driven hopping with initial manual alignment.

A free-running hardware timer on each node increments a counter every 500 ms, and all nodes derive the current channel from this counter using HOPPING_CHANNELS[counter mod 6]. This ensures nodes remain synchronized as long as their counters match. Testing revealed that the hardware timers exhibit negligible drift: no measurable desynchronization occurred over 3 hours of continuous operation.

For initial alignment, a dedicated Sync screen allows users to manually synchronize two units before a chat or audio session. This one-time manual step initializes both counters to the same value, after which the hardware timer maintains alignment automatically.

### 3.4 Channel Access (CSMA)

Since multiple packet types share the link, ordinary transmissions use Carrier Sense Multiple Access (CSMA): before transmitting, the radio briefly listens, if the channel is busy, it backs off for a random 1-10 ms interval and retries, up to five times. Real-time audio is the exception it deliberately bypasses CSMA backoff because millisecond level stalls would starve the audio pipeline.

## 4 The Packet Protocol and Data Link

Every transmission, regardless of type, is a fixed 32-byte frame, the maximum nRF24L01+ payload. A single frame format multiplexing all traffic is what lets text, voice and control share one hopping radio.

### 4.1 Packet Format

src_node_id
1 Byte

dst_node_id
1 Byte

type + fec
2 Bytes

data
28 Bytes
Figure 7: 32-byte packet format, 2-byte header + 28-byte payload

The 4-byte header contains two 1-byte address fields (src_node_id and dst_node_id) and a 2-byte bit-field packing packet_type (4 bits) with fec metadata (12 bits), leaving 28 bytes for payload. One-byte node IDs address packets, with 0xFF reserved for broadcast. An RF test ping or sync beacon can thus reach all nodes simultaneously.

struct __attribute__((packed)) FHSSPacket {
uint8_t | src_node_id; | // sender
uint8_t | dst_node_id; | // 0xFF = broadcast
uint16_t packet_type : 4; | // PONG / CHAT / AUDIO / ND_SYNC / TEST / ACK
uint16_t fec : 12; | // scheme | XOR block id | slot index
uint8_t | data[28]; | // payload (CRC in the last 2 bytes)
};

Listing 2: C definition of the 32 byte packet: 4 byte header with bit packed fields + 28 byte payload

### 4.2 The Payload Region and the FEC Convention

A strict project-wide convention governs the 28-byte data region, ensuring the framing and error-control layers never overlap:

- For protected packets, the last 2 bytes of data hold a CRC-16, leaving 26 user bytes
- Reliable (ARQ) packets further use the first 2 of those 26 bytes for a sequence number, leaving 24 application bytes
- The 12-bit fec header field carries metadata only (scheme type, XOR block/slot identifiers), never the CRC itself, which would not fit in 12 bits

This single fixed layout allows one read() path to demultiplex all six packet types and deliver the correct payload to each application.

## 5 Forward Error Correction

The radio’s built in CRC and auto-acknowledgement are disabled, error control is handled entirely by the custom FEC subsystem in the transceiver. This design choice allows tailoring the error control mechanism to each traffic type, as different applications require different guarantees. The subsystem combines three complementary mechanisms.

### 5.1 The Three Mechanisms

- CRC-16-CCITT (detection): Every protected packet carries a 16-bit checksum in the last two payload bytes. On receipt, the CRC is recomputed, a mismatch indicates corruption and the packet is silently dropped. This transforms a noisy link into a clean-or-nothing channel.
- ARQ (retransmission): For chat, which is infrequent but must be exact, the sender attaches a sequence number, transmits, and waits for an ACK, retransmitting on a 200 ms timeout up to three times. The receiver only ACKs after safely buffering the message, ensuring lost frames are re-sent rather than falsely confirmed. ARQ guarantees delivery but blocks briefly, so it is used only where latency is not critical.

- XOR block code (forward recovery): For audio, which is real-time and cannot tolerate retransmission delays, the sender groups every four data packets and transmits a fifth parity packet equal to their bitwise XOR. If any one packet in a block is lost, the receiver reconstructs it by XOR-ing the four packets it did receive. Loss recovery operates in the forward direction only.

// TX: accumulate a running parity across the data slots of a block. for (uint8_t b = 0; b < FEC_USER_SIZE; b++)
parity[b] ^= pkt.data[b];

// After FEC_XOR_BLOCK_SIZE (=4) data packets, emit the parity packet. if (++count >= FEC_XOR_BLOCK_SIZE)
transmitAudioPacket(parityPkt); // lets RX rebuild one lost packet

Listing 3: XOR forward error correction: parity packet is the bitwise XOR of four data packets, enabling reconstruction of any single lost packet

### 5.2 Per-Type Policy

Each packet type is matched to the mechanism that fits its needs:

Type | CRC | ARQ | XOR | Rationale
CHAT | ✓ | ✓ | ✗ | Infrequent; must be exact.
AUDIO | ✓ | ✗ | ✓ | Real-time; forward recovery only.
PONG | ✓ | ✗ | ✗ | Frequent; ARQ would backlog.
ACK | ✓ | ✗ | ✗ | Small control packet.
ND_SYNC | ✗ (raw) | ✗ | ✗ | Must stay forgiving for resync.
TEST | ✗ (raw) | ✗ | ✗ | Must measure real bit errors.

Table 1: Error Handling Strategy for Each Packet Type

TEST packets are sent completely raw so the BER screen measures the true channel error rate rather than a CRC-filtered version.

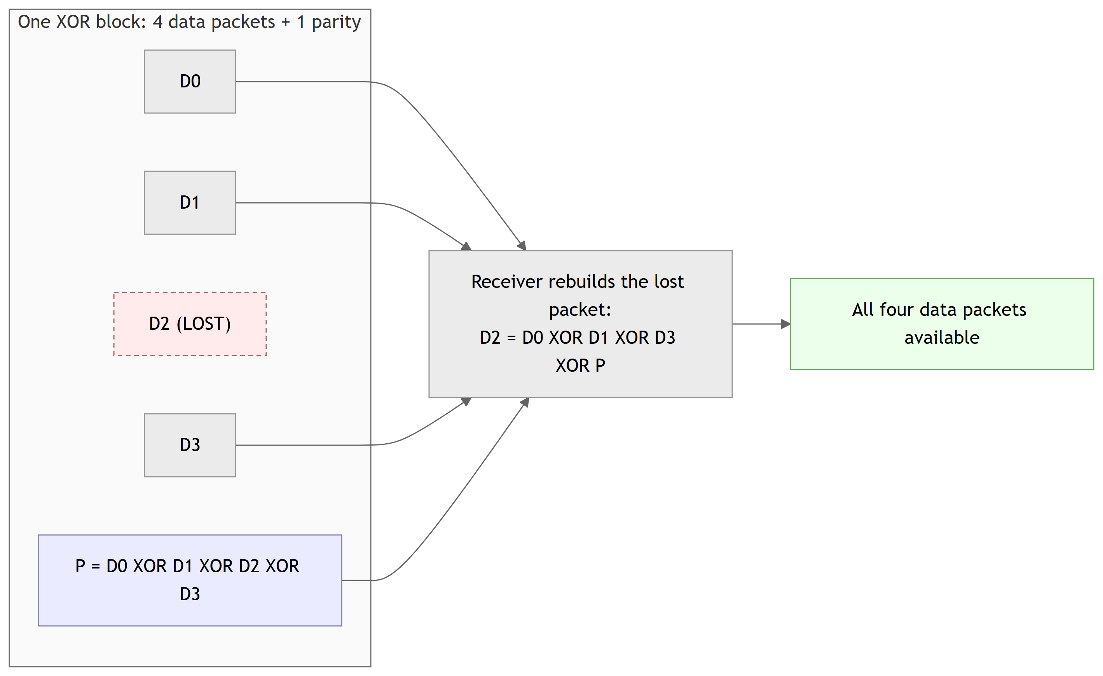
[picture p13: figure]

Figure 8: XOR block forward error correction packet reconstruction

## 6 Real-Time Audio

The audio mode turns the pair into a half-duplex walkie-talkie: one node talks, the other listens, and the Select button toggles the role. It is the most demanding feature because live voice must coexist with channel hopping that interrupts the link every 500 ms.

### 6.1 Format and Capture

Voice is captured from the INMP441 as 8 kHz, 8-bit mono PCM—deliberately lowfidelity but sufficient for intelligible speech while keeping the data rate low at 64 kbps. The microphone is read over I2S without blocking. Each sample is then conditioned in software: a running DC-offset estimate (exponential moving average) is subtracted, a gain factor is applied, and the result is clamped to 8 bits. Twenty-four conditioned samples (3 ms of audio) are packed into one AudioPayload, exactly filling the 26-byte protected user region.

### 6.2 Transport and Playback

Each payload is passed to audioTx, which wraps it with CRC + XOR-block FEC and transmits it, bypassing CSMA backoff. On the listening side, recovered payloads arrive through audioRx and are written into a large ring buffer that absorbs network jitter. Samples are then drained to the DAC at a precise 8 kHz using micros() timing. No additional hardware timer is needed because the hop counter already uses one.

### 6.3 Non-Blocking Pipeline

The entire chain capture, conditioning, transmission, reception, and playback—consists of short cooperative steps pumped from the main loop. Since nothing blocks, FHSS hopping continues uninterrupted while audio flows. The XOR FEC is particularly important here: at a hop boundary, the in-flight packet is often lost, but the block code transparently rebuilds it, smoothing what would otherwise be an audible click every 500 ms.

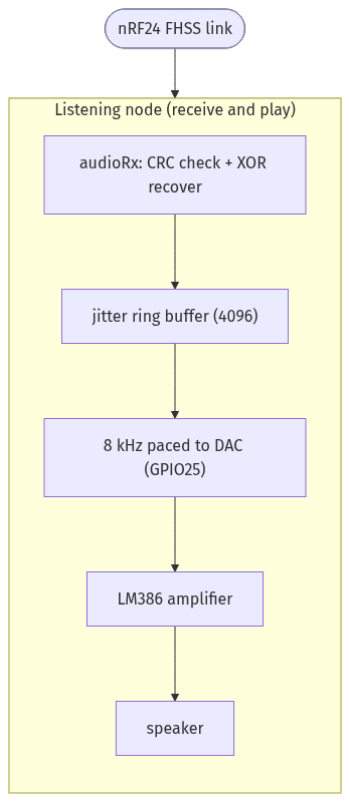
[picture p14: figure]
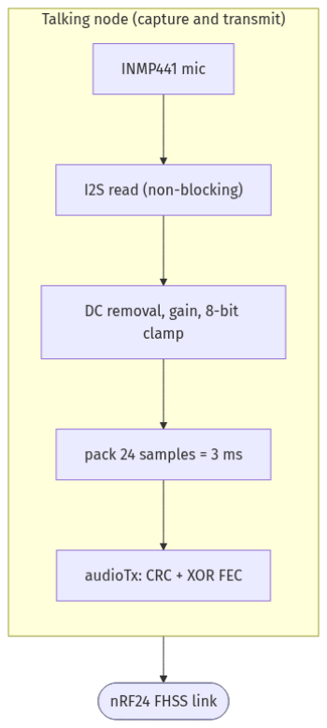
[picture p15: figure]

Figure 9: Non-blocking real-time audio pipeline from microphone to speaker

## 7 Security and Applications

### 7.1 Text Confidentiality

Chat text passes through a lightweight XOR stream cipher before transmission and is decrypted on receipt, protecting the message over the air. Combined with the unknown hopping sequence this provides a basic layer of confidentiality. It is important to note that this is obfuscation rather than strong cryptography. A stronger, authenticated cipher such as AES would be a clear security improvement.

### 7.2 Applications

Five screens exercise the stack:

- Sync: manually synchronizes two units by aligning their hop counters before a communication session
- Chat: encrypted text, sent point-to-point (reliable: ARQ + CRC) or broadcast (CRC only), displayed on a scrolling OLED log
- Audio: half-duplex walkie-talkie
- Pong: a two-player real-time game where paddle/ball updates validate low-latency bidirectional traffic over the hopping link
- RF/BER Test: a diagnostic mode that measures raw channel error rates

## 8 Testing, Results and Analysis

### 8.1 Method

Two diagnostic instruments are built into the firmware. First, the RF/BER test sends raw, known-pattern packets (repeated 0xAB) at a fixed rate, the receiver echoes them back, and both sides count sent, received, echoed, and corrupt packets. Since TEST packets bypass FEC, this measures the true channel error rate. Second, the transceiver maintains live FEC counters (CRC pass/fail, ARQ sent/retransmitted/acked/failed, and audio blocks/recovered/lost), printed as a throttled serial summary. Together, these tools separate raw link quality from FEC recovery performance.

### 8.2 Results

To isolate the effect of frequency hopping, the RF/BER test was run twice on the same hardware and channel set: once with FHSS enabled, and once with hopping disabled so both nodes remained on a single fixed channel. Over 1000 transmitted packets in each configuration, the difference is clear:

Metric | FHSS | No FHSS (fixed channel)
Packets sent | 1000 | 1000
Packets delivered | 854 (85.4%) | 480 (48.0%)
Packets lost | 146 (14.6%) | 520 (52.0%)
Bit-error rate (BER) (%) | 1 | 19

Table 2: Link reliability with and without frequency hopping (RF/BER test, same hardware and channel set)

Beyond the raw channel, the three error-control layers were measured from the transceiver’s live FEC counters during representative sessions: a text chat (which uses CRC + ARQ) and a real-time audio call (which uses CRC + XOR block recovery). The values below are cumulative totals across both nodes.

ARQ (reliable chat) | Value
Reliable messages sent | 32
Delivered (ACK received) | 29 (90.6%)
Failed after full retransmission | 3 (9.4%)
Retransmissions triggered | 9
Corrupt messages delivered (caught by CRC) | 0

Table 3: ARQ reliability over a chat session (CRC + ARQ), both nodes combined

XOR + CRC (real-time audio) | Value
XOR blocks processed | 9,255
Packets rebuilt by XOR parity | 516
Packets lost (unrecoverable) | 17,161
Corrupt packets dropped by CRC | 2,027
Packets passing CRC | 23,798

Table 4: Forward error correction over an audio session (CRC + XOR block code), both nodes combined

### 8.3 Analysis

Frequency hopping is the single biggest contributor to link reliability. On the fixed channel, more than half of the packets (52%) were lost and the bit-error rate reached 19%, because any persistent interferer on that one frequency corrupts every transmission. Spreading the same traffic across six hopping channels cut the loss to 14.6% and the BER to 1%, since only the few hops that coincide with an interferer are affected. Hopping turns a barely usable link into a usable one.

The error-control layers then act on top of the channel, and each behaves as designed. ARQ recovered transient losses through retransmission and delivered 29 of 32 chat messages; the three that failed did so only after exhausting their full retransmission budget, so they were reported as failed rather than silently dropped. CRC delivered zero corrupt chat messages, and during the much noisier audio session it detected and discarded 2,027 corrupted packets, keeping garbage out of the speaker.

The XOR block code shows both its value and its limit. It rebuilt 516 audio packets with no retransmission at all, which is exactly the forward recovery that real-time voice needs. However, 17,161 packets were lost beyond recovery: the parity packet can only repair one erasure per block of four, and the un-buffered audio link tends to drop several packets at each 500 ms hop boundary, so most damaged blocks lose more than one slot and cannot be reconstructed. This matches the audible glitching noted among the challenges, and points to a larger receive buffer or a stronger code as the clearest next improvement.

## 9 Challenges and How We Tackled Them

- Synchronization: The most significant challenge. After evaluating various approaches, we implemented timer-driven hopping with manual initial alignment. A dedicated Sync screen aligns counters before communication, after which the hardware timer maintains synchronization automatically.
- Pong: was initially running on an extremely low framerate due to having to process packets while rendering to the screen at the same time. The fix was simple, transmit packets less often since the most important aspect is the effect of the nodes on the ball position, not the paddle’s position.
- Audio pipeline: initially too slow, causing signal overlap and transmission delays. The solution involved reworking the DAC buffer to drop old samples and bypassing CSMA backoff for audio packets.
- CSMA stalling real-time audio: The 1-10 ms CSMA backoff, suitable for chat, starved the audio pipeline and caused choppy playback. Audio transmission now bypasses backoff. Collisions are acceptable because the mode is half-duplex and FEC-protected.

## 10 Limitations and Future Work

- Synchronization requires manual initial alignment via the Sync screen. Automatic synchronization was considered but deferred due to time constraints.
- The nRF24L01+ modules proved unreliable. We had to test multiple units to find functional ones, and they occasionally drop packets.

## 11 Conclusion

FELCOM demonstrates that jam-resistant text and voice communication can be built on inexpensive hardware. Six-channel FHSS with timer-driven synchronization (manual initial alignment, then stable) provides the foundation, while layered FEC (CRC, ARQ, XOR) and a non-blocking design ensure reliability. Hardware limitations —notably nRF24L01+ inconsistencies and the lightweight XOR cipher—are acknowledged. Future work could add AES encryption and automated synchronization, turning this prototype into a resilient off-grid communication solution.

## 12 References

[1] Nordic Semiconductor, nRF24L01+ Single Chip 2.4 GHz Transceiver Product Specification.
[2] Espressif Systems, ESP32 Technical Reference Manual and ESP32 Series Datasheet.
[3] InvenSense (TDK), INMP441 Omnidirectional Microphone with Bottom Port and I2S Digital Output, Datasheet.
[4] Texas Instruments, LM386 Low Voltage Audio Power Amplifier, Datasheet.
[5] TMRh20, RF24: Optimized Driver for nRF24L01(+) on Arduino & Raspberry Pi (open-source library).
[6] H. K. Markey (Lamarr) and G. Antheil, Secret Communication System, U.S. Patent 2,292,387, 1942.
[7] ITU-T Recommendation V.41, Code-independent error-control system (CRC-16-CCITT).
[8] A. Goldsmith, Wireless Communications, Cambridge University Press (spread spectrum and FHSS fundamentals).

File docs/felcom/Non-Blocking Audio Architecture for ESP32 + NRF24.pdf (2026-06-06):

# Non-Blocking Audio Architecture for ESP32 + NRF24

## Goal

Integrate real-time audio streaming into a larger ESP32 application without using FreeRTOS tasks.

The existing project already uses hardware timers and other time-sensitive systems, so audio should operate using a cooperative, non-blocking architecture that can be called from the main loop.

Instead of multiple RTOS tasks, the system will be organized into update functions and circular buffers.

# Design Philosophy

The original implementation used:

micTask()
nrfTask()
dacTask()

These tasks continuously ran in parallel.

For integration into a larger codebase, this approach can become difficult to manage because:

Multiple execution contexts exist
Timing becomes harder to reason about
Debugging becomes more difficult
Interactions with other subsystems become less predictable

Instead, the recommended architecture is:

loop()
├── updateAudioCapture()
├── updateRadioTx()
├── updateRadioRx()
├── updateAudioPlayback()
├── updateUI()
├── updateGame()
├── updateTimers()
└── updateInputs()

•
•
•

•
•
•
•

Each subsystem executes quickly and returns immediately.

No function should block.

# System Overview

## Transmitter

Audio flow:

INMP441
↓
I2S DMA
↓
updateAudioCapture()
↓
Audio Ring Buffer
↓
updateRadioTx()
↓
NRF24

## Receiver

Audio flow:

NRF24
↓
updateRadioRx()
↓
Audio Ring Buffer
↓
Timer Driven DAC Output
↓
GPIO25 DAC
↓
LM386
↓
Speaker

# Circular Buffer Design

The ring buffer becomes the key component.

It decouples:

Audio acquisition
Radio transmission
Radio reception
Audio playback

Without requiring separate tasks.

Example:

#define AUDIO_BUFFER_SIZE 2048

uint8_t audioBuffer[AUDIO_BUFFER_SIZE];

volatile uint16_t head = 0;
volatile uint16_t tail = 0;

Functions:

bool audioAvailable();
bool audioSpaceAvailable();

void pushAudio(uint8_t sample);
uint8_t popAudio();

The ring buffer allows timing differences between subsystems without blocking execution.

# Transmitter Design

## updateAudioCapture()

Purpose:

Read microphone samples from I2S Remove DC offset
Apply gain
Convert to 8-bit PCM

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
Push samples into transmit buffer

Called continuously from loop().

Example:

void updateAudioCapture()
{
size_t bytesRead;

i2s_read(
I2S_NUM_0,
i2sBuf,
sizeof(i2sBuf),
&bytesRead,
0
);

if(bytesRead == 0)
return;

processSamples();
}

Important:

The timeout argument is:

0

instead of:

portMAX_DELAY

This guarantees the function never blocks.

## Audio Processing

For each microphone sample:

•

### 1. Extract sample

sample24 = i2sBuf[i] >> 8;

### 2. Remove DC offset

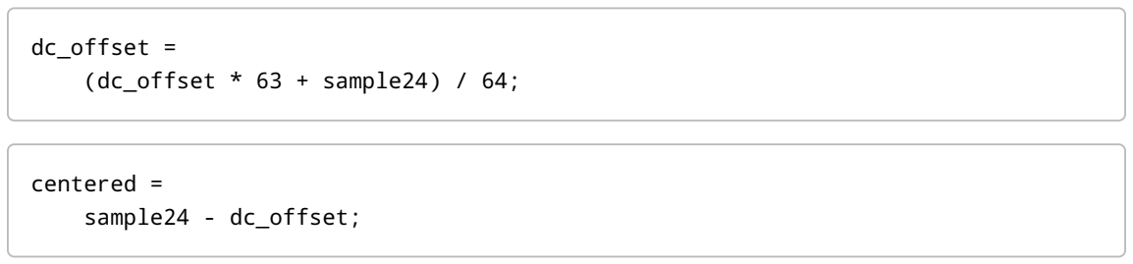
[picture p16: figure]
dc_offset = (dc_offset * 63 + sample24) / 64;; centered = sample24 - dc_offset;

### 3. Apply gain

scaled =
(centered * GAIN) >> 16;

### 4. Convert to DAC-compatible range

value = 128 + scaled;

### 5. Clamp

0 | ≤ | value | ≤ | 255

### 6. Push to transmit buffer

pushAudio(value);

## updateRadioTx()

Purpose:

Build NRF24 packets whenever enough audio samples are available.

Packet format:

Byte 0 : Sequence Number
Byte 1-31 : Audio Samples

Called continuously from loop().

Example:

void updateRadioTx()
{
while(audioAvailable())
{
packet[idx++] = popAudio();

if(idx == 32)
{
packet[0] = seq++;

radio.writeFast(packet, 32);

idx = 1;
}
}
}

Characteristics:

Non-blocking
No delays
No RTOS task

# Receiver Design

## updateRadioRx()

Purpose:

Receive packets and store samples into playback buffer.

Called continuously from loop().

Example:

•
•
•

void updateRadioRx()
{
while(radio.available())
{
radio.read(packet,32);

for(int i=1;i<32;i++)
{
pushAudio(packet[i]);
}
}
}

Characteristics:

Non-blocking
Drains radio FIFO quickly
Returns immediately when no packets exist

# Audio Playback

Audio playback requires precise timing.

The DAC must receive one sample every:

1 / 8000
=
125 microseconds

Using delays inside loop() is not recommended.

# Hardware Timer Driven Playback

•
•
•

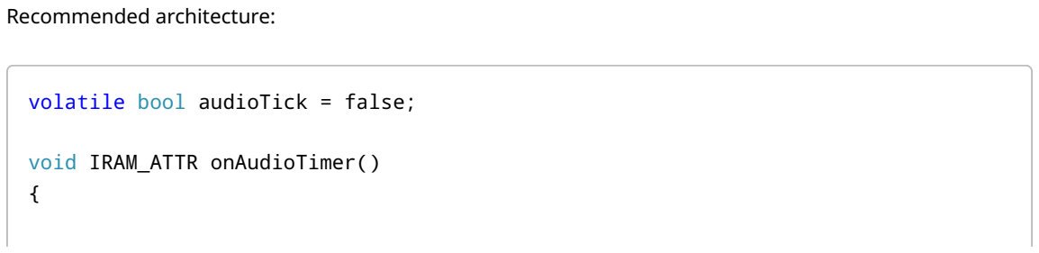
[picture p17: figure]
Recommended architecture:; volatile bool audioTick = false;; void IRAM_ATTR onAudioTimer() {

audioTick = true;
}

Timer frequency:

8000 Hz

Period:

125 microseconds

## updateAudioPlayback()

Called from loop().

void updateAudioPlayback() {
if(!audioTick)
return;

audioTick = false;

if(ringTail != ringHead)
{
dac_output_voltage(
DAC_CHANNEL_1,
ring[ringTail]
);

ringTail =
(ringTail + 1)
& RING_MASK;
}
else
{
dac_output_voltage(
DAC_CHANNEL_1,
128
);
}
}

Benefits:

Precise playback rate
Non-blocking
Easy integration

# Alternative: DAC Inside Timer ISR

An even simpler architecture is possible.

The timer ISR can directly output samples.

Example:

void IRAM_ATTR onAudioTimer() {
if(ringTail != ringHead)
{
dac_output_voltage(
DAC_CHANNEL_1,
ring[ringTail]
);

ringTail =
(ringTail + 1)
& RING_MASK;
}
else
{
dac_output_voltage(
DAC_CHANNEL_1,
128
);
}
}

In this design:

Main loop only fills buffers
Playback timing is completely hardware-driven

This is often the preferred solution for simple voice communication systems.

•
•
•

•
•

# Main Loop Structure

Final architecture:

void loop()
{
updateAudioCapture();

updateRadioTx();

updateRadioRx();

updateAudioPlayback();

updateUI();

updateButtons();

updateGameLogic();

updateTimers();
}

Characteristics:

No delays
No blocking reads
No RTOS tasks
Deterministic execution
Easy integration with existing systems

# Important Timing Notes

Audio playback must remain:

8000 Hz

or

16000 Hz

•
•
•
•
•

depending on the chosen sample rate.

A timer running at:

1000 Hz

or

100 Hz

cannot directly drive audio playback.

Audio should have:

Its own hardware timer, or
A timer already configured at the required audio sample rate

# Advantages of the Non-Blocking Architecture

Compared to the original RTOS implementation:

Easier integration into existing projects Fewer execution contexts
Deterministic behavior
Simpler debugging
Lower scheduling overhead
Better compatibility with custom timing systems No task watchdog issues
No FreeRTOS dependency for audio processing

# Summary

The recommended integration strategy is to replace the original audio tasks with a cooperative update-based architecture.

Audio capture, radio transmission, radio reception, and playback all operate through shared ring buffers and non-blocking update functions.

Precise playback timing is maintained using a dedicated hardware timer running at the audio sample rate.

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
This preserves the original functionality while making the audio subsystem significantly easier to integrate into larger ESP32 applications.

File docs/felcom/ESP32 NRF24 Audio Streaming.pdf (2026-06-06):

# ESP32 + NRF24 Real-Time Audio Streaming Architecture

## Overview

This project implements a real-time wireless audio link between two ESP32 DevKit V1 boards using:

INMP441 I2S microphone
NRF24L01+ PA/LNA radio modules
ESP32 internal DAC (GPIO25)
LM386 audio amplifier

The system continuously captures audio on the transmitter, packetizes it, sends it over the NRF24 link, and immediately reconstructs and plays the audio on the receiver.

The implementation prioritizes:

Low latency
Simplicity
Real-time streaming
Minimal RAM usage

No audio compression is currently used. Raw 8-bit audio samples are transmitted directly.

# Hardware

## Transmitter

INMP441 Connections

INMP441 | ESP32
VDD | 3.3V
GND | GND
L/R | GND
SCK | GPIO13
WS | GPIO16
SD | GPIO17

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
NRF24 Connections

NRF24 | ESP32
CE | GPIO4
CSN | GPIO5
MOSI | SPI MOSI
MISO | SPI MISO
SCK | SPI SCK

## Receiver

NRF24 Connections

Same as transmitter.

Audio Output

ESP32 | Function
GPIO25 | DAC output

GPIO25 connects to the LM386 amplifier input through a resistor divider.

# Audio Pipeline

## Transmitter Side

Audio flow:

INMP441 → I2S → DSP Processing → Packet Builder → NRF24

Step 1: Audio Capture

The INMP441 microphone produces 24-bit audio samples.

The ESP32 receives these through I2S.

Configuration:

8000 Hz sample rate
Mono
32-bit I2S transfers
Left channel only

The microphone continuously fills DMA buffers.

Step 2: DC Offset Removal

INMP441 microphones usually contain a DC bias.

An exponential moving average is used:

dc_offset = (dc_offset * 63 + sample) / 64

Each sample is centered:

centered = sample - dc_offset

This prevents the audio waveform from drifting away from zero.

Step 3: Gain

The centered microphone signal is amplified in software.

Example:

scaled = (centered * GAIN) >> 16

Typical gain values:

16
24
32

Higher gain increases volume but also increases noise and clipping risk.

Step 4: Convert to 8-Bit Audio

The ESP32 DAC accepts values from:

•
•
•
•

•
•
•

0 to 255

with:

128 = silence

The microphone signal is converted:

value = 128 + scaled

Then clamped:

0 ≤ value ≤ 255

This produces a stream of unsigned 8-bit audio samples.

Step 5: Packet Formation

NRF24 packets are fixed at 32 bytes.

Packet layout:

Byte 0:

Sequence number

Bytes 1-31:

Audio samples

Structure:

[SEQ][AUDIO][AUDIO][AUDIO]...[AUDIO]

This allows:

31 audio samples per packet

At 8000 Hz:

8000 samples/sec

8000 / 31 ≈ 258 packets/sec

•

•

Step 6: Transmission

Each packet is sent immediately:

radio.write(packet, 32)

The transmitter continuously streams packets.

No buffering of complete recordings is performed.

This creates a live audio stream.

# Receiver Side

Audio flow:

NRF24 → Ring Buffer → DAC → LM386 → Speaker

## Step 1: Receive Packets

The receiver constantly polls:

radio.available()

When a packet arrives:

radio.read(packet, 32)

The sequence byte is ignored unless packet-loss detection is desired.

## Step 2: Push Audio Into Ring Buffer

Each packet contains:

31 audio samples

These samples are copied into a circular buffer.

Example:

packet[1] packet[2] ... packet[31]

↓

ring buffer

The ring buffer absorbs small timing variations in radio delivery.

## Step 3: DAC Playback

A dedicated playback task runs at:

8000 Hz

Each cycle:

Pull one sample from ring buffer Output sample to DAC GPIO25

Example:

dac_output_voltage(DAC_CHANNEL_1, sample);

If the ring buffer is empty:

dac_output_voltage(DAC_CHANNEL_1, 128);

which outputs silence.

## Ring Buffer Design

A ring buffer is used to separate:

Radio timing

from

Audio playback timing

Without the ring buffer:

Radio packet jitter would directly create audio glitches.

The ring buffer acts as a small reservoir of audio samples.

1.
2.

# FreeRTOS Tasks

## Transmitter

micTask

Responsibilities:

Read I2S microphone
Remove DC offset
Apply gain
Convert to 8-bit samples
Fill NRF packets
Transmit packets

Runs on:

Core 0

## Receiver

nrfTask

Responsibilities:

Receive packets
Extract audio samples
Push samples into ring buffer

Runs on:

Core 0

dacTask

Responsibilities:

Maintain exact playback rate Read ring buffer
Feed DAC

Runs on:

Core 1

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
Keeping playback isolated improves timing stability.

# Audio Characteristics

Current format:

8000 Hz sample rate
Mono
8-bit unsigned PCM

Bandwidth:

8000 samples/sec × 8 bits

≈ 64 kbps audio

This is suitable for:

Voice
Walkie-talkie style communication Intercom applications

Not suitable for:

Music
High-fidelity audio

# Known Limitations

## Packet Loss

Current implementation does not recover lost packets.

If a packet is missed:

31 audio samples are lost.

This produces a brief click or dropout.

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
## No Compression

Every audio sample consumes one byte.

Future versions may use:

IMA ADPCM
µ-law
Delta encoding

to increase range and reliability.

## NRF24 Throughput Limits

The design intentionally uses:

8000 Hz audio
1 Mbps radio mode

to remain within the practical throughput limits of NRF24 modules.

Higher audio rates may increase latency and packet loss.

# Future Improvements

Potential upgrades:

Sequence number tracking
Packet-loss concealment
Voice activity detection
Audio compression (ADPCM)
Dynamic gain control
Noise gate
Low-pass filtering
Push-to-talk support
Multiple-node audio routing Encrypted audio packets

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
# Summary

The system implements a simple real-time wireless audio stream:

INMP441 captures audio.
ESP32 converts microphone data to 8-bit PCM.
Samples are packed into 32-byte NRF24 packets.
NRF24 transmits packets continuously. Receiver stores samples in a ring buffer.
DAC outputs audio through GPIO25.
LM386 amplifies the signal for a speaker.

The architecture is intentionally simple and serves as a solid base for integrating voice communication into larger ESP32 projects.

1.
2.
3.
4.
5.
6.
7.

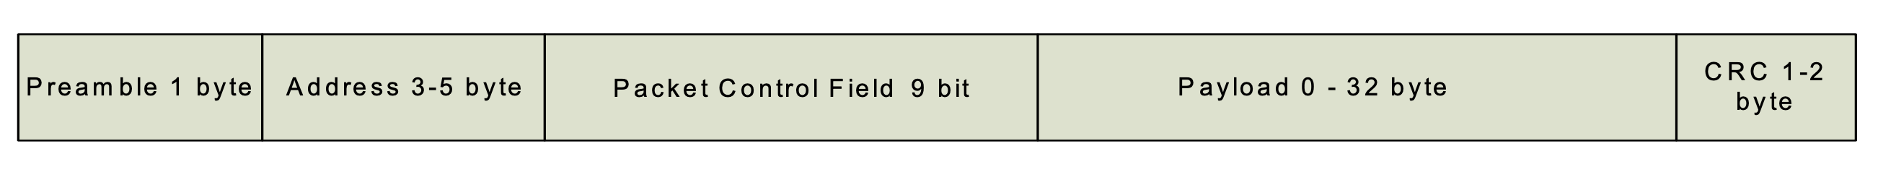
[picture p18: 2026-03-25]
FELCOM/assets/Enhanced shockburst packet.png

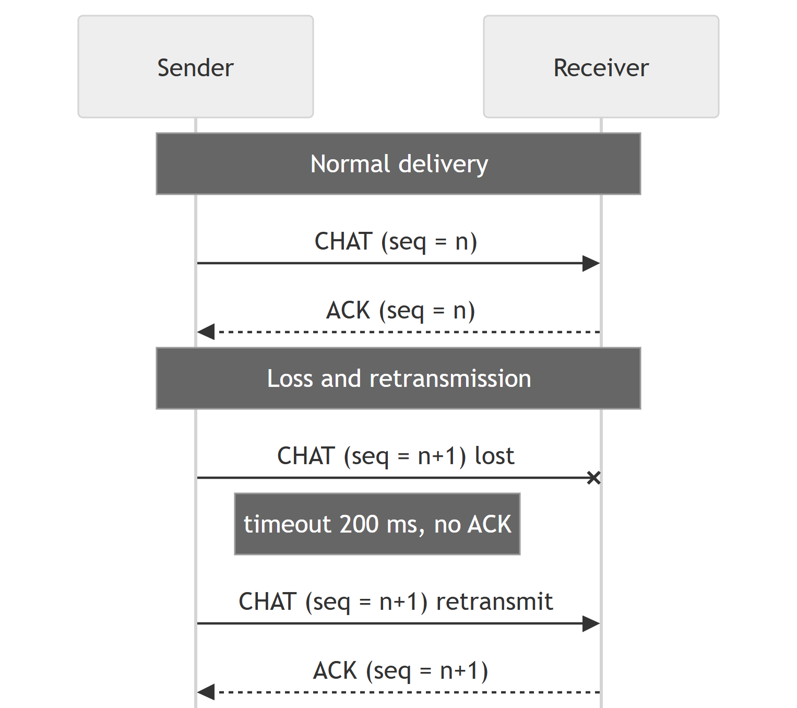
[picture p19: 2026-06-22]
docs/diagrams/arq.png

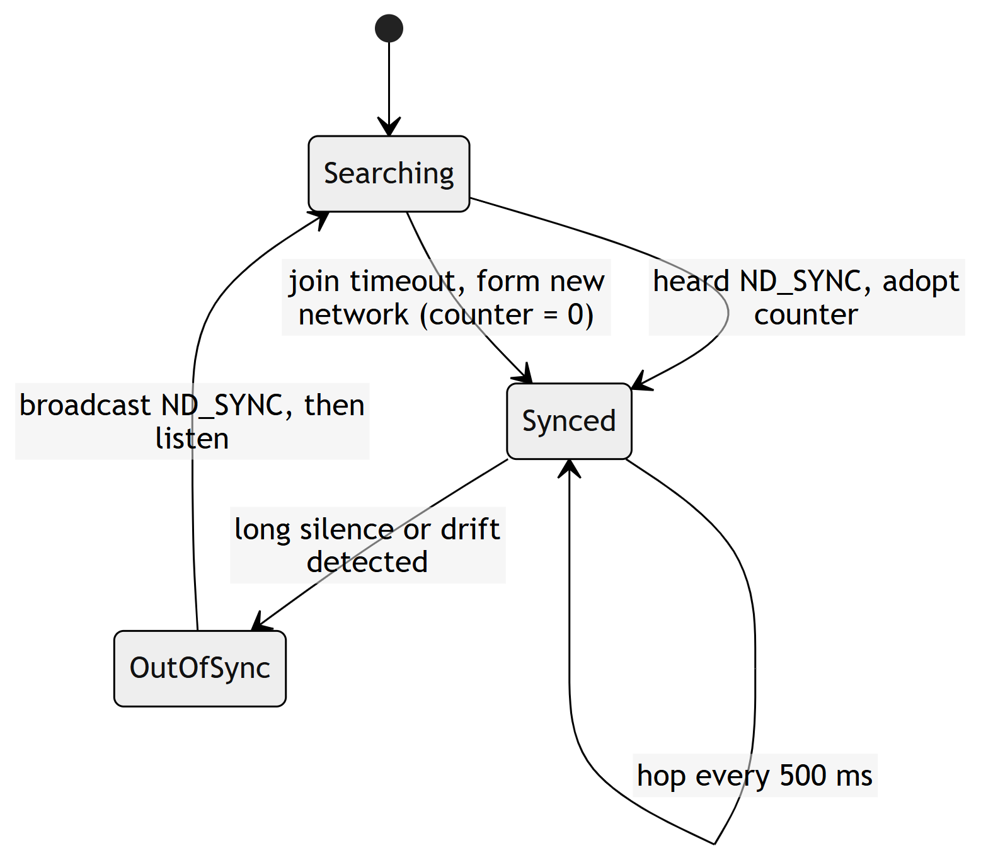
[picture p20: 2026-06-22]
docs/diagrams/sync-fsm.png

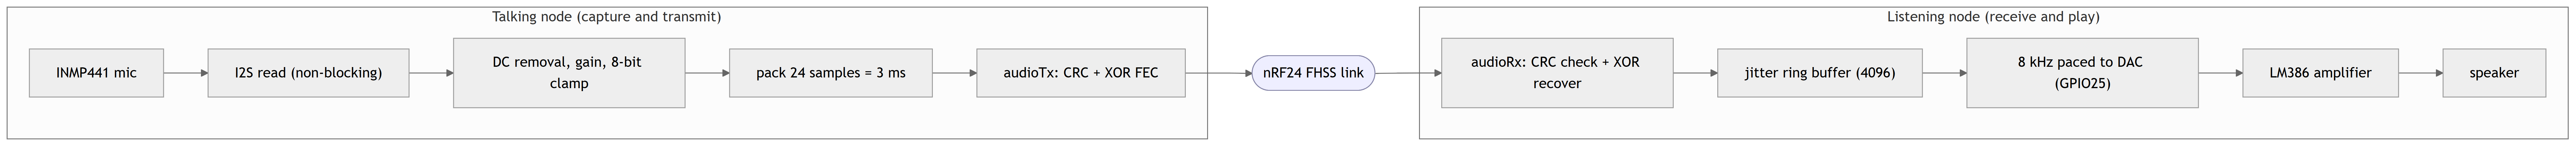
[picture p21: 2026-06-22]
docs/diagrams/audio-pipeline.png

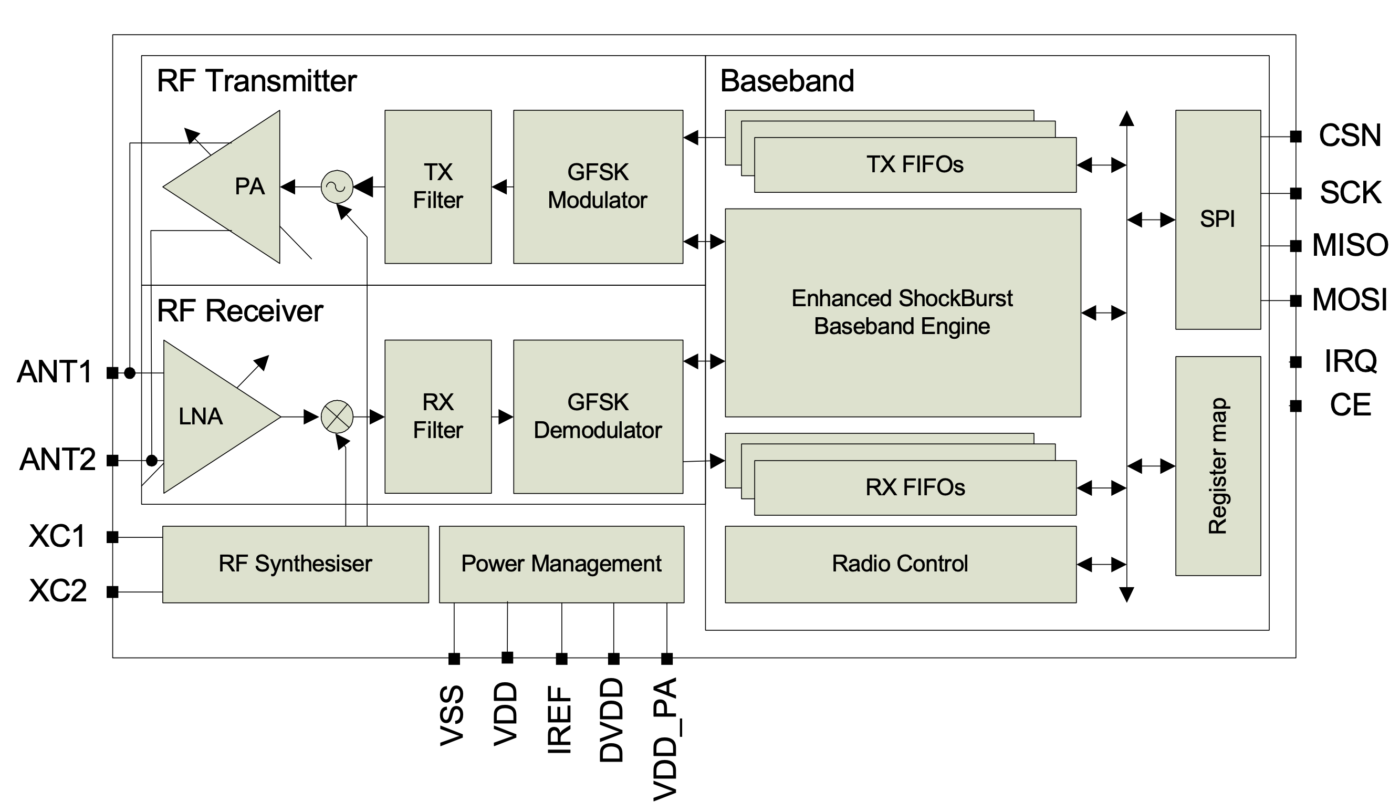
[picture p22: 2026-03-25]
FELCOM/assets/nRF24L01 block diagram.png

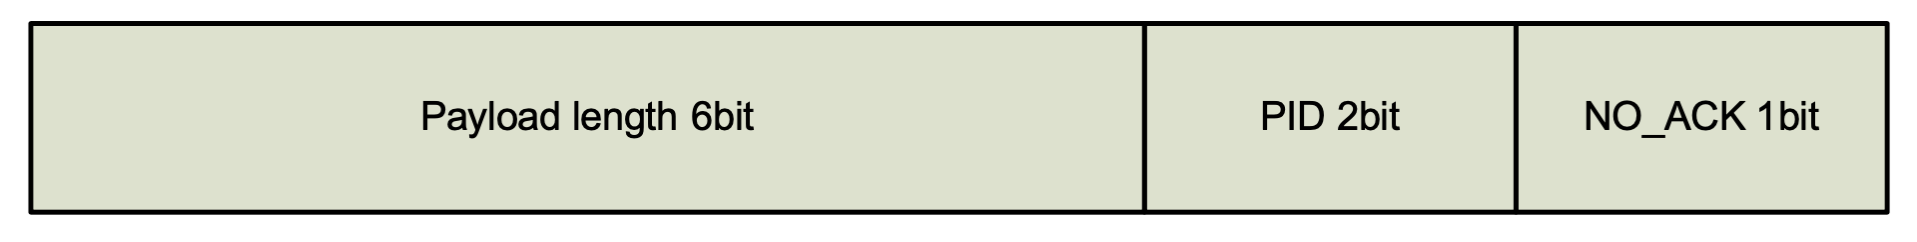
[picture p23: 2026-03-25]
FELCOM/assets/Packer Control Field.png

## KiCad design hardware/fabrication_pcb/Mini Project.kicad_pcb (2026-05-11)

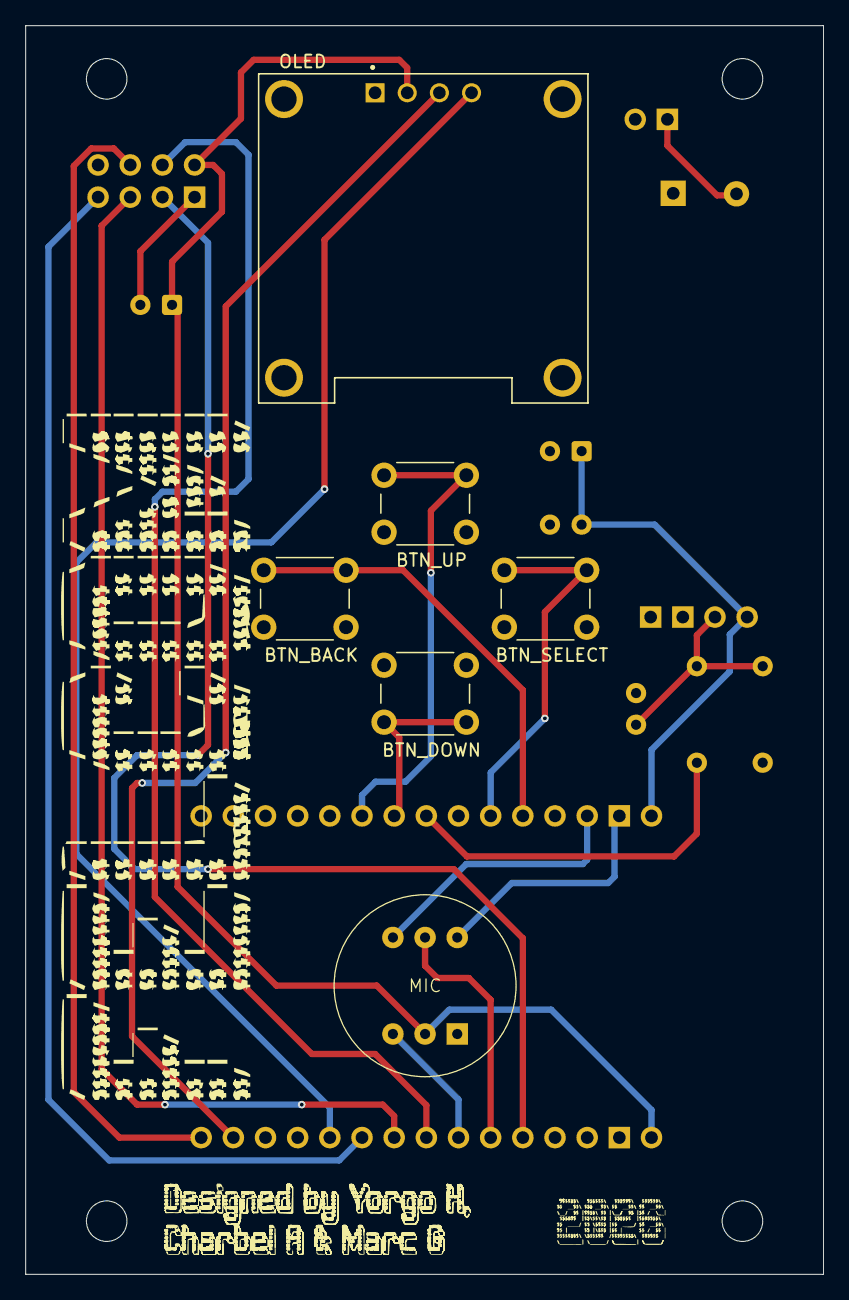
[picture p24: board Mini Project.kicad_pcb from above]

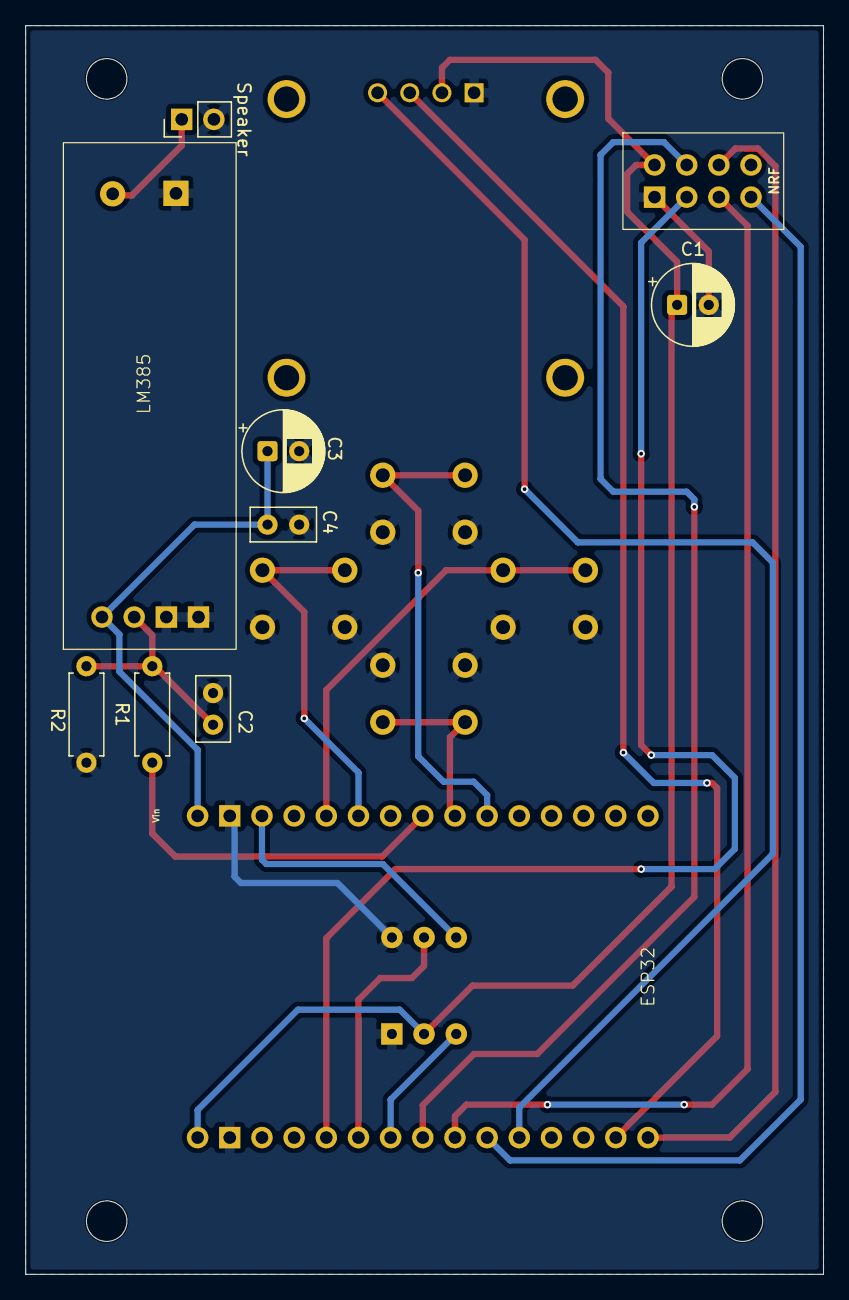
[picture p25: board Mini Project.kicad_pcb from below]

Board: 2 copper layers, 63.0 x 98.6 mm, 20 parts (10 on the bottom side), 20 nets.

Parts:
C1, C3: 47uF; CP_Radial_D6.3mm_P2.50mm
C2, C4: 100nF; C_Disc_D5.0mm_W2.5mm_P2.50mm
ESP32: ESP32_DevKit_V1_30pin
H1, H2, H3, H4: MountingHole; MountingHole_3.2mm_M3
J1: Speaker; PinHeader_1x02_P2.54mm_Vertical
LM385: AMP; LM386_MODULE
MIC: MIC; MH-ET_I2S_MICROPHONE_MODULE
OLED : OLED Display; MODULE_DM-OLED096-636
R1: 10K; R_Axial_DIN0207_L6.3mm_D2.5mm_P7.62mm_Horizontal
R2: 1K; R_Axial_DIN0207_L6.3mm_D2.5mm_P7.62mm_Horizontal
S1: BTN_UP; SW_PUSH_6mm
S2: BTN_DOWN; SW_PUSH_6mm
S3: BTN_SELECT; SW_PUSH_6mm
S4: BTN_BACK; SW_PUSH_6mm
nrf1: NRF24L01_PA_LNA

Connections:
+3.3V: C1.1, ESP32.1 (3V3), MIC.2 (VCC), OLED.2 (VCC), nrf1.2 (VCC)
+5V: C3.1, C4.1, ESP32.16 (VIN), LM385.1 (VCC)
BTN_BACK: ESP32.20 (D14), S4.1
BTN_DOWN: ESP32.24 (D33), S2.2
BTN_SELECT: ESP32.21 (D27), S3.1
BTN_UP: ESP32.25 (D32), S1.1
CE: ESP32.5 (D4), nrf1.3 (CE)
CSN: ESP32.8 (D5), nrf1.4 (CSN)
GND: C1.2, C2.2, C3.2, C4.2, ESP32.2 (GND), ESP32.17 (GND), J1.2, LM385.3 (GND), LM385.4 (GND), LM385.6 (GND), MIC.3 (GND), MIC.4 (L/R), OLED.1 (GND), R2.2, S1.2, S2.1, S3.2, S4.2, nrf1.1 (GND)
MISO: ESP32.10 (D19), nrf1.7 (MISO)
MOSI: ESP32.15 (D23), nrf1.6 (MOSI)
unnamed: J1.1, LM385.5 (OUT)
unnamed: C2.1, LM385.2 (IN), R1.2, R2.1
SCK: ESP32.9 (D18), nrf1.5 (SCK)
SCK_M: ESP32.18 (D13), MIC.6 (SCK)
SCL: ESP32.14 (D22), OLED.3 (SCK)
SD: ESP32.7 (D17), MIC.1 (SD)
SDA: ESP32.11 (D21), OLED.4 (SDA)
WS: ESP32.6 (D16), MIC.5 (WS)
dac_out: ESP32.23 (D25), R1.1

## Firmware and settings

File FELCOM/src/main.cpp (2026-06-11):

#include <config.h>
#include <debug.h>
#include <display.h>
#include <encryption.h>
#include <input.h>
#include <string.h>
#include <ftimers.h>
#include <selected_destination.h>
#include <transceiver.h>

#include "audio.h"
#include "chat/ChatMessage.h"
#include "chat/chat.h"
#include "pong/pong.h"
#include "rf_test/testMode.h"
#include "ui/AudioUI.h"
#include "ui/MenuUI.h"
#include "ui/PongUI.h"
#include "ui/RFTestUI.h"
#include "ui/SessionTargetUI.h"
#include "ui/SyncTestUI.h"
#include "ui/ui.h"

transceiver xcvr;
ChatHandler chat;
PongGame pong;
ui appUI;

uint8_t SELECTED_DST_NODE = BROADCAST_DST_NODE;
static bool gTargetUIActive = false;
static UIMode gPendingMode = UIMode::Chat;

void setup() {
    loggerSetup();
    // LOG_INFO("Booting node (id=0x%02X)", NODE_ID);

    setupDisplay();
    // LOG_INFO("Display ready");

    inputInit();

    initCounter();

    xcvr.setup();
    xcvr.setChannel(HOPPING_CHANNELS[readCounter() % HOPPING_CHANNELS_SIZE]);
    xcvr.setMode(RECEIVE);
    LOG_INFO("Transceiver ready");

    audio::begin(&xcvr);  // I2S mic (stereo slot0) + DAC; idle until AUDIO screen

    chat.init();
    initializeGame(&pong);
    appUI.init(&chat, &pong);
    // LOG_INFO("Boot complete");
}

void loop() {
    static uint32_t lastHop = 0;
    uint32_t currentHop = readCounter() % HOPPING_CHANNELS_SIZE;
    if (currentHop != lastHop) {
        lastHop = currentHop;
        xcvr.setChannel(HOPPING_CHANNELS[currentHop]);
        xcvr.setMode(RECEIVE);
        // Skip the serial log during audio — flush() stalls ~50 ms and glitches
        // playback. The hop itself still happens.
        if (appUI.mode != UIMode::Audio) {
            LOG_INFO("Hopped to channel %d", HOPPING_CHANNELS[currentHop]);
        }
    }

    // Throttled FEC summary; suppressed in audio mode (a blocking serial flush
    // would interrupt real-time playback). The AUDIO screen has its own opt-in
    // debug line below.
    static uint32_t lastFecStatsMs = 0;
    if (appUI.mode != UIMode::Audio && millis() - lastFecStatsMs >= 5000) {
        lastFecStatsMs = millis();
        xcvr.logFecStats();
    }

    int8_t dir = inputDirectionY();
    bool btnDown = inputButtonPressed();
    bool backDown = inputBackPressed();

    if (gTargetUIActive) {
        if (backDown) {
            gTargetUIActive = false;
            appUI.setMode(UIMode::Menu);
            return;
        }

        bool confirmed = false;
        if (sessionTargetUITickInput(xcvr, dir, btnDown, SELECTED_DST_NODE,
                                     &SELECTED_DST_NODE, &confirmed)) {
            sessionTargetUIUpdate(xcvr);
        }

        if (confirmed) {
            gTargetUIActive = false;
            appUI.setMode(gPendingMode);
        }
        return;
    }

    if (backDown && appUI.mode != UIMode::Menu) {
        gTargetUIActive = false;
        appUI.setMode(UIMode::Menu);
    }

    switch (appUI.mode) {
        case UIMode::Menu:
            if (menuUIUpdateSelection(dir)) {
                appUI.onMenuSelectionChanged();
            }
            if (btnDown) {
                MenuModeSelection selection = menuUIGetSelection();
                if (selection == MenuPong) {
                    gPendingMode = UIMode::Pong;
                    gTargetUIActive = true;
                    sessionTargetUIInitDisplay(xcvr, SELECTED_DST_NODE);
                } else if (selection == MenuChat) {
                    gPendingMode = UIMode::Chat;
                    gTargetUIActive = true;
                    sessionTargetUIInitDisplay(xcvr, SELECTED_DST_NODE);
                } else if (selection == MenuSyncTest) {
                    gTargetUIActive = false;
                    appUI.setMode(UIMode::SyncTest);
                } else if (selection == MenuAudio) {
                    gPendingMode = UIMode::Audio;
                    gTargetUIActive = true;
                    sessionTargetUIInitDisplay(xcvr, SELECTED_DST_NODE);
                } else if (selection == MenuAbout) {
                    gTargetUIActive = false;
                    appUI.setMode(UIMode::About);
                } else {
                    gTargetUIActive = false;
                    appUI.setMode(UIMode::RFTest);
                }
            }
            break;
        case UIMode::Chat:
            if (chat.input.tickJoystick(dir, btnDown)) {
                appUI.onChatInputChanged();
            }

            // send
            if (chat.input.hasMessage()) {
                ChatMessage msg;
                chat.input.popMessage(msg, NODE_ID);
                chat.log.push(msg);

                encrypt(msg.text, sizeof(msg.text));

                bool ok = selectedDestinationIsBroadcast()
                              ? xcvr.write(PacketType::CHAT, msg,
                                           SELECTED_DST_NODE)
                              : xcvr.writeReliable(PacketType::CHAT, msg,
                                                   SELECTED_DST_NODE);

                (void)ok;

                appUI.onChatMessageAdded();
            }

            // receive — one read, one push
            ChatMessage incoming;
            if (xcvr.read(PacketType::CHAT, incoming)) {
                decrypt(incoming.text, sizeof(incoming.text));

                //LOG_INFO("Packet from 0x%02X: %s", incoming.senderId,
                //         incoming.text);
                chat.log.push(incoming);
                appUI.onChatMessageAdded();
            }

            break;
        case UIMode::Pong:
            if (pongUITickInput(&pong, dir, btnDown)) {
                appUI.onPongStateChanged();
            }
            break;
        case UIMode::RFTest:
            if (rfTestUITickInput(xcvr, dir, btnDown, millis())) {
                appUI.onRFTestStateChanged();
            }
            break;
        case UIMode::SyncTest:
            if (syncTestUITickInput(xcvr, dir, btnDown, millis(),
                                    readCounter())) {
                appUI.onSyncTestStateChanged();
            }
            break;
        case UIMode::Audio:
            // Pumps capture/TX (talking) or RX/playback (listening) every loop.
            if (audioUITickInput(dir, btnDown)) {
                appUI.onAudioStateChanged();
            }
#if AUDIO_SERIAL_DEBUG
            // Serial printing stalls the cooperative audio loop, so keep this
            // compile-time disabled except while diagnosing the audio path.
            {
                static uint32_t lastAudioDbg = 0;
                if (millis() - lastAudioDbg >= 2000) {
                    lastAudioDbg = millis();
                    audio::Stats s = audio::stats();
                    Serial.printf(
                        "\nAUDIO %s tx=%lu rx=%lu i2s=%lu/%lu mic=%lu "
                        "peak=%ld clip=%lu/%lu ring=%u under=%lu over=%lu | ",
                        audio::isTalking() ? "TALK" : "LISTEN",
                        (unsigned long)s.txPayloads,
                        (unsigned long)s.rxPayloads,
                        (unsigned long)(s.i2sReads - s.i2sEmptyReads),
                        (unsigned long)s.i2sReads,
                        (unsigned long)s.micSamples,
                        (long)s.micPeak,
                        (unsigned long)s.micClippedLow,
                        (unsigned long)s.micClippedHigh,
                        s.rxLevel,
                        (unsigned long)s.rxUnderruns,
                        (unsigned long)s.rxOverruns);
                    xcvr.logFecStats();
                }
            }
#endif
            break;
        case UIMode::About:
            // About has no active input right now besides back button
            break;
        default:
            return;
    }

    // Keep this empty unless active section needs periodic redraws.
    // delay(30);
}

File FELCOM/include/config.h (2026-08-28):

#ifndef CONFIG_H
#define CONFIG_H
#include <stdint.h>

// NODE config
#ifndef FELCOM_VERSION
#define FELCOM_VERSION "unknown"
#endif
// change for each device flashed
#ifndef NODE_ID
#define NODE_ID 'B'
#endif

// Debug config
#define DEBUG 1
#define DEBUG_SERIAL Serial
#define DEBUG_BAUD 9600

// Interference Testing Mode
#define TEST_PATTERN 0xAB
#define RF_TEST_PACKET_SIZE 28
#define RF_TEST_DELAY_MS 1000

// NRF24L01 config
#define NRF24L01_CE_PIN 4
#define NRF24L01_CSN_PIN 5
#define NRF24L01_POWER_LEVEL RF24_PA_MAX
#define NRF24L01_DATA_RATE RF24_1MBPS
// nodes needs to be on the same PHY to talk to each other
// MAX 5
#define NRF24L01_PHY_ADDR 0
// ADDR 0 and 1 will store a full 5-byte address.
// ADDR 2-5 will technically only store a single byte, borrowing up to 4
// additional bytes from pipe 1 per the assigned address width
const uint8_t PHY_ADDRESSES[6][6] = {"FELCO", "GELCO", "HELCO",
                                     "JELCO", "KELCO", "LELCO"};

#define HOPPING_CHANNELS_SIZE 6
const uint8_t HOPPING_CHANNELS[HOPPING_CHANNELS_SIZE] = {110, 111, 112,
                                                         113, 114, 115};

// Chat Config
// Shrunk from 25/22 so the chat wire frame (2B seq + msg + 2B CRC) fits the
// 28-byte data[] region once the FEC layer reserves seq + CRC. See fec.md.
#define MAX_INPUT_LENGTH 18
#define LOG_SIZE 10
#define MSG_MAX_TEXT 18

// Encryption Config
#define XOR_KEY {0xBB, 0x7A, 0x67, 0x99}
#define XOR_KEY_LEN 4

// button inputs
#define BTN_UP_PIN 32
#define BTN_DOWN_PIN 33
#define BTN_SELECT_PIN 27
#define BTN_BACK_PIN 14


// Screen config
#define I2C_ADDR 0x3C
#define SCREEN_WIDTH 128
#define SCREEN_HEIGHT 64
#define SCREEN_SDA_PIN 21
#define SCREEN_SCL_PIN 22

// INMP441 I2S Microphone
#define I2S_PORT I2S_NUM_0
#define I2S_SCK_PIN 13  // Serial clock
#define I2S_WS_PIN 16   // Word select
#define I2S_SD_PIN 17   // Serial data in
// L/R: wire to GND on module, no GPIO needed

// DAC output (receiver side only)
#define DAC_OUT_PIN 25  // ESP32 DAC1 (GPIO25) — matches the audio amp wiring

// Audio config
#define AUDIO_SAMPLE_RATE 8000   // Hz
#define AUDIO_PACKET_SAMPLES 24  // seq(2) + samples(24) = 26 user bytes (FEC_AUDIO_SAMPLES)
// 0 = disabled, 1 = TX (mic), 2 = RX (speaker), 3 = both if ever needed
#define AUDIO_ENABLED 1
// INMP441 L/R tied to GND selects the left I2S slot. With ESP32 legacy I2S in
// RIGHT_LEFT mode, boards/libraries can disagree on whether that arrives as
// buffer index 0 or 1. If mic diagnostics show near-zero level, try changing
// this between 0 and 1 before changing gain.
#define AUDIO_I2S_SLOT_INDEX 0
// Software mic gain: scaled = (centered * AUDIO_GAIN) >> 16.
//   higher = louder but more clipping/hiss; lower = cleaner but quieter.
//   Tune by ear: try 12 / 18 / 24 / 32.
#define AUDIO_GAIN 8
// Set to 1 to hear locally the same 8-bit mic samples being transmitted while
// TALKING. Useful for checking mic/I2S/gain before debugging the radio link.
#define AUDIO_LOCAL_MONITOR 0
// Max local monitor backlog while TALKING. Lower = less sidetone delay; if too
// low it can sound rough because old samples are dropped to stay live.
#define AUDIO_LOCAL_MONITOR_MAX_QUEUED 24
// Set to 0 to test only the mic -> local DAC path without nRF24/FEC blocking.
// Leave 1 for normal walkie-talkie TX.
#define AUDIO_RADIO_TX_ENABLE 1
// Set to 1 for serial audio diagnostics. Keep 0 for normal playback: serial
// printing stalls the cooperative audio loop and causes audible glitches.
#define AUDIO_SERIAL_DEBUG 0
// DAC playback ring (power of two; smooths radio jitter in LISTEN and paces the
// local mic monitor in TALK).
#define AUDIO_RX_RING 4096

// FEC config — see "FEC Prototype — Design Document" (fec.md)
#define FEC_XOR_BLOCK_SIZE 4    // data packets per XOR block (+1 parity packet)
#define FEC_ARQ_TIMEOUT_MS 200  // wait for ACK before retransmit
#define FEC_ARQ_MAX_RETRIES 3   // max ARQ retransmissions
#define FEC_AUDIO_RX_QUEUE 8    // recovered audio payloads buffered for playback

// Pong config
#define PONG_SCORE_TO_WIN 7
#define PONG_TICK_MS 30
#define PONG_TX_INTERVAL_MS 15

#endif  // CONFIG_H

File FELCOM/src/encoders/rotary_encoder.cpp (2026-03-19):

#include "encoders.h"

// Variables to hold the current and last encoder position
volatile int encoderPos = 0;
volatile int lastEncoderPos = 0;

// Variables to keep track of the state of the pins
volatile int lastCLK;
volatile int currentCLK;
volatile unsigned long lastButtonInterruptMs = 0;

constexpr unsigned long BUTTON_DEBOUNCE_MS = 10;

void ARDUINO_ISR_ATTR readEncoder();
void ARDUINO_ISR_ATTR encoderButtonPressed();

void setupRotaryEncoder()
{
    pinMode(ROTARY_ENCODER_CLK_PIN, INPUT_PULLUP);
    pinMode(ROTARY_ENCODER_DT_PIN, INPUT_PULLUP);
    pinMode(ROTARY_ENCODER_SW_PIN, INPUT_PULLUP);

    attachInterrupt(digitalPinToInterrupt(ROTARY_ENCODER_CLK_PIN), readEncoder, CHANGE);
    attachInterrupt(digitalPinToInterrupt(ROTARY_ENCODER_SW_PIN), encoderButtonPressed, FALLING);

    // Read the initial state of CLK
    lastCLK = digitalRead(ROTARY_ENCODER_CLK_PIN);
}

// Interrupt service routine for reading the encoder
void ARDUINO_ISR_ATTR readEncoder()
{
    currentCLK = digitalRead(ROTARY_ENCODER_CLK_PIN);
    // If the current state of CLK is different from the last state
    // then a pulse occurred
    if (currentCLK != lastCLK)
    {
        // If the DT state is different from the CLK state
        // then the encoder is rotating clockwise
        if (digitalRead(ROTARY_ENCODER_DT_PIN) != currentCLK)
        {
            encoderPos++;
#if defined(ROTARY_ENCODER_CW_CALLBACK)
            ROTARY_ENCODER_CW_CALLBACK();
#endif
        }
        else
        {
            // Otherwise, it's rotating counterclockwise
            encoderPos--;
#if defined(ROTARY_ENCODER_CCW_CALLBACK)
            ROTARY_ENCODER_CCW_CALLBACK();
#endif
        }
    }
    // Update lastCLK with the current state for the next pulse detection
    lastCLK = currentCLK;
}

void ARDUINO_ISR_ATTR encoderButtonPressed()
{
    const unsigned long nowMs = millis();
    if ((nowMs - lastButtonInterruptMs) < BUTTON_DEBOUNCE_MS)
    {
        return;
    }

    lastButtonInterruptMs = nowMs;
#if defined(ROTARY_ENCODER_SW_CALLBACK)
    ROTARY_ENCODER_SW_CALLBACK();
#endif
}

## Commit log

2026-03-06 Initial commit: NRF + ESP32 testing code
2026-03-06 Added ESP32 NRF testing code
2026-03-19 feat: add rotary encoder, some improvements to pong
2026-03-19 Added kicad schematic for easy assembly
    [miniProject.kicad_pcb, miniProject.kicad_sch]
2026-03-21 feat!: move drivers to the lib folder
    fix includes in project
    fix functions defined moved to cpp file, heder only contains declaration
    [config.h, main.cpp, pong.h]
2026-03-22 fix(build success): solved and doc build solution
    [config.h, main.cpp]
2026-03-22 feat!: complete texting (screen bug)
    [config.h, main.cpp]
2026-03-22 fix: thrice message issue
    [config.h]
2026-03-24 Added speaker circuitry
    [miniProject.kicad_sch]
2026-03-24 fix: minor convenience fixes
    [miniProject.kicad_sch]
2026-03-24 feat: add documentation about the wireless module
2026-03-27 test:trying to find fixes
    [config.h]
2026-04-02 fix: BER menu with BER 5% MAX
    [config.h, main.cpp]
2026-04-16 feat: add tiny pcb test
    [miniProject.kicad_pcb, miniProject.kicad_sch]
2026-04-17 feat: ¯\_(ツ)_/¯
2026-04-17 fix: rcv menu size
    [config.h]
2026-04-17 fix: remove unnecessary include from config.h
    [config.h]
2026-04-17 fix: update menu on selection don't init, fix typo in enum
    [main.cpp]
2026-04-17 fix: added line in main
    [main.cpp]
2026-04-22 feat: added button controls
2026-04-23 feat: added basic pcb layout
    [Mini Project.kicad_pcb, Mini Project.kicad_sch]
2026-04-23 feat: very bad basic routing
    [Mini Project.kicad_pcb, Mini Project.kicad_sch]
2026-04-24 fix: minor pcb stuff
    [Mini Project.kicad_pcb]
2026-04-29 feat:added button mode
2026-05-01 feat: dynamic version, back button returns to main menu
2026-05-04 feat: added completed pcb - thanks yorgi
    [Mini Project.kicad_pcb, Mini Project.kicad_sch, miniProject.kicad_pcb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]
2026-05-04 feat: exported gerbers
    [Mini Project-B_Cu.gbr, Mini Project-B_Mask.gbr, Mini Project-B_Paste.gbr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]
2026-05-04 update footprints and symbols
    [Mini Project.kicad_pcb, Mini Project.kicad_sch]
2026-05-04 fix: symbols and footprints per project
2026-05-05 feat: updated pcb layout
    [Mini Project.kicad_pcb, Mini Project.kicad_sch]
2026-05-06 fix: schematic looking fancy, component placement done
    [Mini Project.kicad_pcb, Mini Project.kicad_sch]
2026-05-06 feat: routed
    [Mini Project.kicad_pcb]
2026-05-06 feat: mount holes
    [Mini Project.kicad_pcb, Mini Project.kicad_sch]
2026-05-07 Feat: silkscreen art
    [Mini Project.kicad_pcb, Mini Project.kicad_sch]
2026-05-07 feat: ORDERED PCBgit add .
    [Mini Project-B_Cu.gbr, Mini Project-B_Mask.gbr, Mini Project-B_Paste.gbr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]
2026-05-11 feat: minor clenaning schematic
2026-05-11 fix: disable fhss, fix formatting and merge artifacts
    [config.h, main.cpp]
2026-05-20 feat: implement FHSS using hardware timer and synchronization
2026-06-06 feat: add FEC print on serial monitor
2026-06-10 Revert "feat: serial debug for microphone"
    This reverts commit 4fbba1663a749d9e18d29b444c52bfc33913aaa9.
    [config.h, main.cpp]
2026-06-11 fix: transmit audio without csma, better dac playback, add local debug
    [config.h, main.cpp]
2026-06-24 docs: tighten report, fix inaccuracies, vendor template
    - Fix claims: drop battery-powered, correct cost (~$95), correct chat
    reliability (broadcast is CRC-only), remove invented FELCOM etymology.
    - Remove standalone Future Work section (folded into the conclusion) and the
    Acknowledgments section.
    - Vendor the starry-ulfg template locally so chapters flow instead of each
    starting a new page, and so the front matter is correct: Table of Contents (i),
    Table of Figures (ii), Abstract (iii) in roman, body from arabic page 1.
    Cuts the report from 24 to 18 pages (~14 content).
2026-06-26 docs: add FELCOM project presentation (PowerPoint)
    Editable 13-slide deck generated from the report: motivation, system overview,
    FHSS, synchronization, packet protocol, FEC, real-time audio, security and
    applications, results (FHSS vs non-FHSS + FEC counters), challenges and future
    work, and conclusion. Figures and claims align with Report.typ.
2026-06-26 docs: align presentation with PowerPoint guidelines
    Add Outline, References and Acknowledgments slides; enforce 22 pt minimum body
    text with brief bullets; merge FHSS + synchronization to stay within 15 slides;
    state future work on the conclusion slide.
2026-06-29 fix: cleanup before demo, sort menu items
    [config.h]
